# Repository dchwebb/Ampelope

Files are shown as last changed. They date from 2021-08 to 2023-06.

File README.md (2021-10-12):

# Ampelope
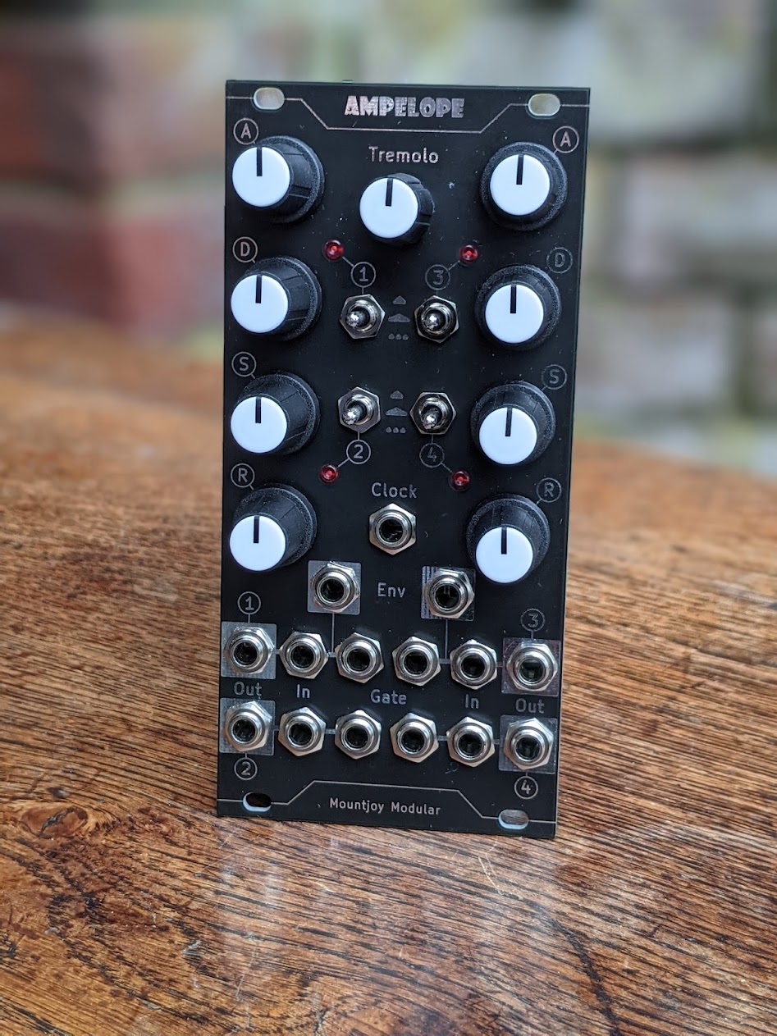
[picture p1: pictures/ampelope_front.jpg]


Overview
--------

Ampelope is a four-channel combined envelope and VCA Eurorack module incorporating a tremolo effect. Each channel can be switched between a fast envelope time, a slow envelope time or a slow envelope with a sine tremolo modulating volume.

The envelopes are loosely modelled on an analog envelope (Roland System 100 type circuit) and feature analog correct capacitor charge/discharge characteristics.

Channels 1 and 2 share the same Attack/Decay/Sustain/Release (ADSR) controls, as do channels 3 and 4. This makes the module particularly suited to dual stereo operation. However each channel has its own gate control allowing independent control of four signals.

The gate controls are normalled in a cascade configuration. For example in dual stereo use gate 1 will be normalled to gate 2 and then a separate gate applied to channel 3 will control channels 3 and 4. In addition gate 1 is normalled to the Doepfer standard gate signal on the 16 pin Eurorack header.

The tremolo control can be clocked or free-run. When clocked the Tremolo potentiometer sets the speed of the tremolo to a multiple of the clock. The tremolo effect applies a sine wave modulation to the envelope.

In addition to the envlopes internal connection to the VCA, envelopes 1 and 3 are available on the front panel and envelopes 2 and 4 on a pin header on the back.

Technical
---------
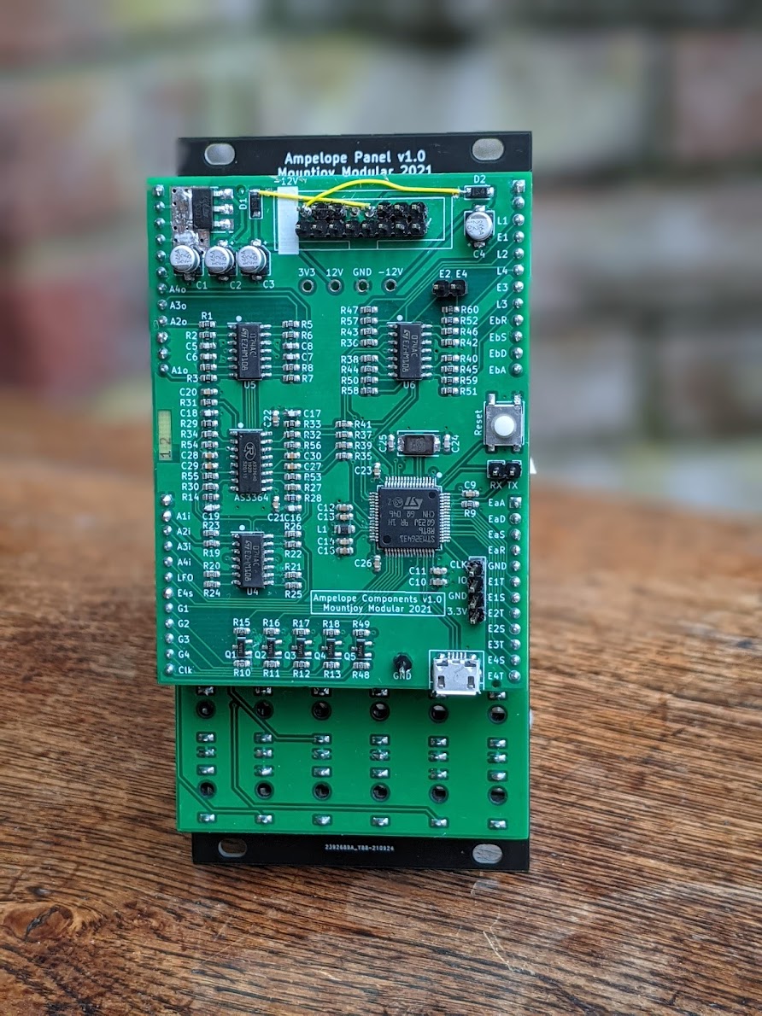
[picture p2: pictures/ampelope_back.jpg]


The module is controlled by an STM32G431 microcontroller which contains four 12-bit DACs. These are used to generate the four envelopes.

The MCU runs at 170MHz and the envelopes samples are generated at 48kHz. The front panel potentiometers are digitised using the MCU's internal ADC. The MCU features a hardware CORDIC peripheral which is used to generate the exponential curves used to model an analog envelopes capacitor charge/discharge characteristics. The CORDIC co-processor is also used to generate the tremolo sine wave.

The MCU's USB peripheral is also connected on the reverse for configuration and upgrade purposes.

The VCA used is an Alpha AS3364 quad linear VCA IC (https://www.alfarzpp.lv/eng/sc/AS3364.php). The MCU outputs the envelopes via its internal DACs at 0V to 3.3V range. This is scaled to 0V to 2V which is the VCA fully closed/fully open range. The envelopes are also amplified to 0V to 8V for control of external modules.

Three TL074 op-amps handle buffering and amplification. NPN transistors provide voltage limiting to incoming gates. The power supply uses a linear regulator to generate the 3.3V digital and analog voltages used by the MCU.

Construction
------------

The module uses a 3 stacked PCB configuration. The components sit on a 4-layer daughter board connected with headers to the 2 layer control PCB holding the LEDs, potentiometers, switches and sockets. This is then bolted to the front panel, also constructed as a 2 layer PCB.

All schematic and PCB layout carried out in Kicad version 5.99.

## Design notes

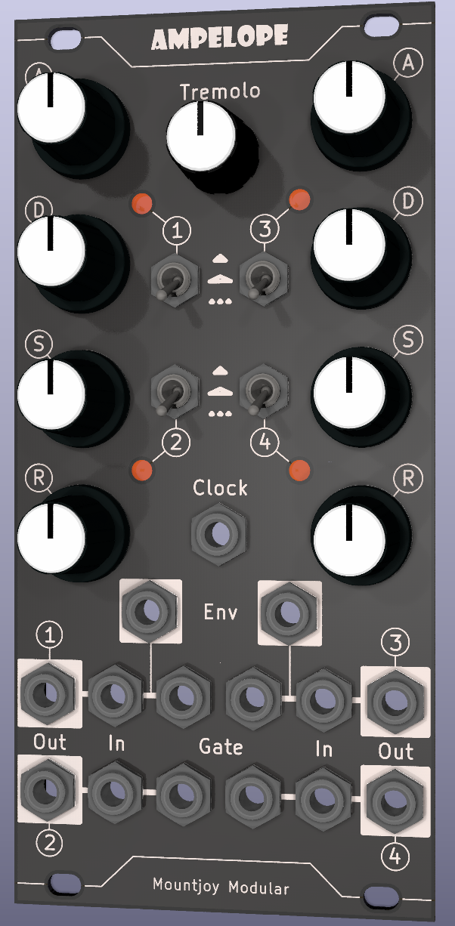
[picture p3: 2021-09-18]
Hardware/Graphics/Ampelope_Panel.png

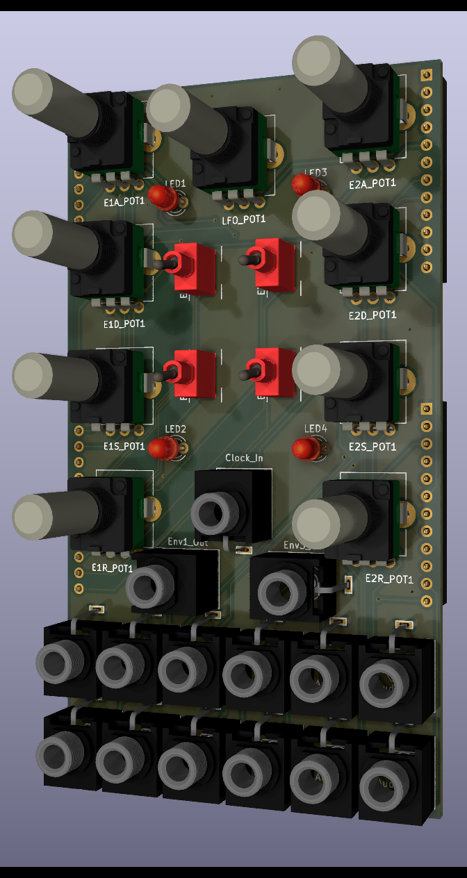
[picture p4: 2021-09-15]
Hardware/Graphics/Ampelope_Controls.png

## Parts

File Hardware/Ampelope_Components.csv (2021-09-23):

Source: | D:\Eurorack\Ampelope\Hardware\Ampelope_Components.kicad_sch
Date: | 22/09/2021 17:17:07
Tool: | Eeschema (5.99.0-12348-g4b436fb86d)
Generator: | C:\Program Files\KiCad\5.99\bin\scripting\plugins/bom_csv_grouped_by_value_with_fp.py
Component Count: | 121
Ref | Qnty | Value | Cmp name | Footprint | Description | Vendor
C1, C2, C3, C4, | 4 | 22uF | CP_Small | Capacitor_SMD:CP_Elec_4x5.8 | Polarized capacitor, small symbol
C5, C6, C7, C8, | 4 | 100pF | C_Small | Capacitor_SMD:C_0603_1608Metric_Pad1.08x0.95mm_HandSolder | Unpolarized capacitor, small symbol
C9, C11, C13, C21, C22, C23, C26, | 7 | 100nF | C_Small | Capacitor_SMD:C_0603_1608Metric_Pad1.08x0.95mm_HandSolder | Unpolarized capacitor, small symbol
C10, | 1 | 4.7uF | C_Small | Capacitor_SMD:C_0603_1608Metric_Pad1.08x0.95mm_HandSolder | Unpolarized capacitor, small symbol
C12, C15, | 2 | 1uF | C_Small | Capacitor_SMD:C_0603_1608Metric_Pad1.08x0.95mm_HandSolder | Unpolarized capacitor, small symbol
C14, C20, | 2 | 10nF | C_Small | Capacitor_SMD:C_0603_1608Metric_Pad1.08x0.95mm_HandSolder | Unpolarized capacitor, small symbol
C16, C17, C18, C19, | 4 | 560pF | C_Small | Capacitor_SMD:C_0603_1608Metric_Pad1.08x0.95mm_HandSolder | Unpolarized capacitor, small symbol
C24, C25, | 2 | 30pF | C_Small | Capacitor_SMD:C_0603_1608Metric_Pad1.08x0.95mm_HandSolder | Unpolarized capacitor, small symbol
C27, C28, C29, C30, | 4 | 2.2nF | C_Small | Capacitor_SMD:C_0603_1608Metric_Pad1.08x0.95mm_HandSolder | Unpolarized capacitor, small symbol
D1, D2, | 2 | 1N5819 | 1N5819 | Diode_SMD:D_SOD-123 | 40V 1A Schottky Barrier Rectifier Diode, DO-41
FID1, | 1 | 4_Layer_Marker | Fiducial | Custom_Footprints:4_Layer_Markers | Fiducial Marker
J1, J2, J3, J4, | 4 | Conn_01x12_Male | Conn_01x12_Male | Connector_PinHeader_2.54mm:PinHeader_1x12_P2.54mm_Vertical | Generic connector, single row, 01x12, script generated (kicad-library-utils/schlib/autogen/connector/)
J5, | 1 | Eurorack_16_pin_power | Eurorack_16_pin_power | Custom_Footprints:Eurorack_16_pin_header
J6, J9, | 2 | Conn_01x02_Male | Conn_01x02_Male | Connector_PinHeader_2.54mm:PinHeader_1x02_P2.54mm_Vertical | Generic connector, single row, 01x02, script generated (kicad-library-utils/schlib/autogen/connector/)
J7, | 1 | SWD_Header | Conn_01x04_Male | Custom_Footprints:SWD_header | Generic connector, single row, 01x04, script generated (kicad-library-utils/schlib/autogen/connector/)
J8, | 1 | USB_B_Micro | USB_B_Micro | Custom_Footprints:USB_Micro-B_Amphenol | USB Micro Type B connector
L1, | 1 | L_Small | L_Small | Inductor_SMD:L_0805_2012Metric_Pad1.05x1.20mm_HandSolder | Inductor, small symbol
Q1, Q2, Q3, Q4, Q5, | 5 | MMBT3906 | MMBT3906 | Package_TO_SOT_SMD:SOT-23 | -0.2A Ic, -40V Vce, Small Signal PNP Transistor, SOT-23
R1, R3, R5, R7, R47, R50, R51, R52, R57, R58, R59, R60, | 12 | 1k | R_Small | Resistor_SMD:R_0603_1608Metric_Pad0.98x0.95mm_HandSolder | Resistor, small symbol
R2, R4, R6, R8, R27, R30, R32, R34, | 8 | 30k | R_Small | Resistor_SMD:R_0603_1608Metric_Pad0.98x0.95mm_HandSolder | Resistor, small symbol
R9, | 1 | 100k | R_Small | Resistor_SMD:R_0603_1608Metric_Pad0.98x0.95mm_HandSolder | Resistor, small symbol
R10, R11, R12, R13, R15, R16, R17, R18, R43, R44, R45, R46, R48, R49, | 14 | 4k7 | R_Small | Resistor_SMD:R_0603_1608Metric_Pad0.98x0.95mm_HandSolder | Resistor, small symbol
R14, R28, R29, R33, | 4 | 510R | R_Small | Resistor_SMD:R_0603_1608Metric_Pad0.98x0.95mm_HandSolder | Resistor, small symbol
R19, R20, R21, R22, R23, R24, R25, R26, R53, R54, R55, R56, | 12 | 10k | R_Small | Resistor_SMD:R_0603_1608Metric_Pad0.98x0.95mm_HandSolder | Resistor, small symbol
R31, | 1 | 100R | R_Small | Resistor_SMD:R_0603_1608Metric_Pad0.98x0.95mm_HandSolder | Resistor, small symbol
R35, R37, R39, R41, | 4 | 6k8 | R_Small | Resistor_SMD:R_0603_1608Metric_Pad0.98x0.95mm_HandSolder | Resistor, small symbol
R36, R38, R40, R42, | 4 | 3k3 | R_Small | Resistor_SMD:R_0603_1608Metric_Pad0.98x0.95mm_HandSolder | Resistor, small symbol
RESET1, | 1 | SW_Push | SW_Push | Custom_Footprints:SW_SPST_EVQQ2 | Push button switch, generic, two pins
TP1, TP2, TP3, TP4, TP5, | 5 | TestPoint | TestPoint | Custom_Footprints:1.3mm_Test_Point | test point
U1, | 1 | STM32G431RB | STM32G431RB | Package_QFP:LQFP-64_10x10mm_P0.5mm | ARM Cortex-M4 MCU, 128KB flash, 32KB RAM, 170MHz, 1.8-3.6V, 50 GPIO, LQFP-64
U2, | 1 | AS3364 | SSI2164 | Package_SO:SOIC-16_3.9x9.9mm_P1.27mm | Quad VCA, SOIC-16
U3, | 1 | LM1117-3.3 | LM1117-3.3 | Package_TO_SOT_SMD:SOT-223-3_TabPin2 | 800mA Low-Dropout Linear Regulator, 3.3V fixed output, TO-220/TO-252/TO-263/SOT-223
U4, U5, U6, | 3 | TL074 | TL074 | Package_SO:SOIC-14_3.9x8.7mm_P1.27mm | Quad Low-Noise JFET-Input Operational Amplifiers, DIP-14/SOIC-14
Y1, | 1 | 8MHz 20pF | Crystal | Crystal:Crystal_SMD_0603-2Pin_6.0x3.5mm | Two pin crystal

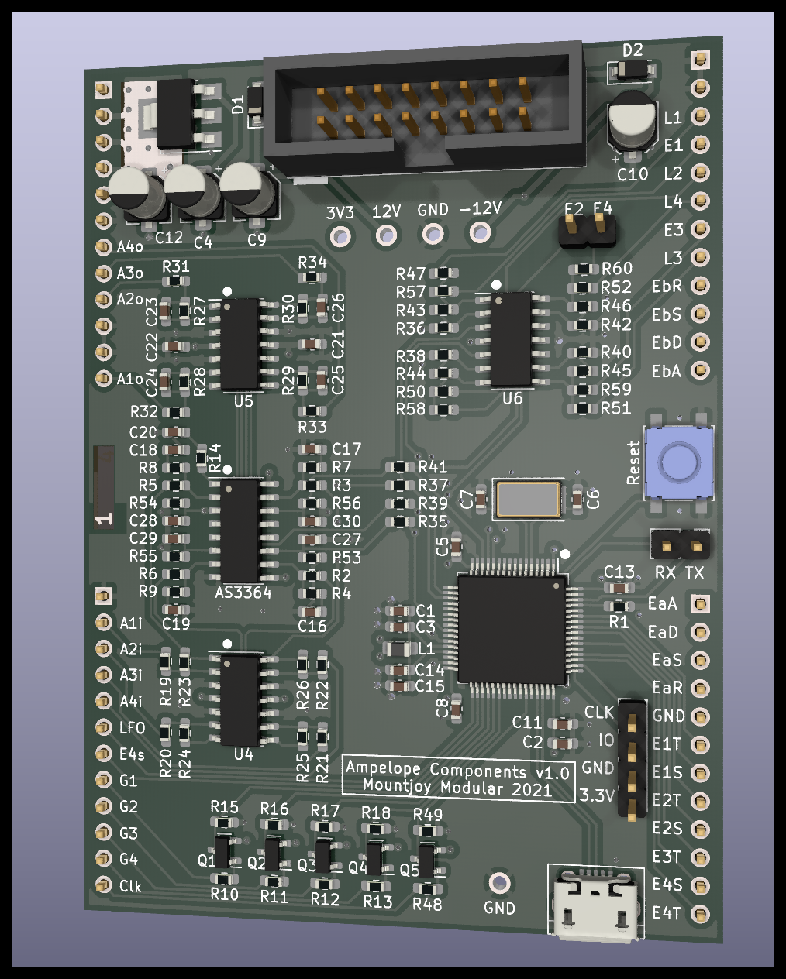
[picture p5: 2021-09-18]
Hardware/Graphics/Ampelope_Components.png

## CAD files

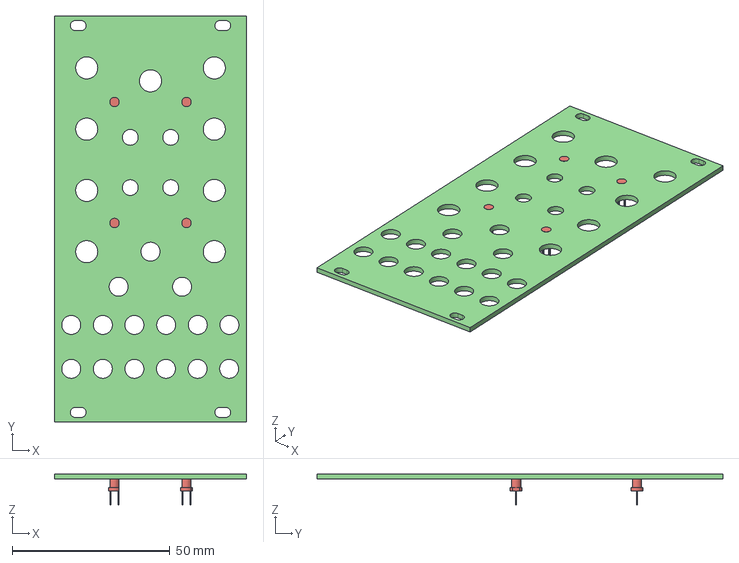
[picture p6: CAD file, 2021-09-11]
Hardware/3d_models/Ampelope_Panel.step
60.8 x 128.5 x 9.80 mm

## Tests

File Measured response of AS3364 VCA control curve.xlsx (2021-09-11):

ctl | output
0 | 0
0.25 | 0.2
0.5 | 1.21
0.75 | 2.8
1 | 4.41
1.25 | 5.89
1.5 | 7.33
1.75 | 8.46
2 | 9.04
Max at around 1.95V
Original signal: 9.65V

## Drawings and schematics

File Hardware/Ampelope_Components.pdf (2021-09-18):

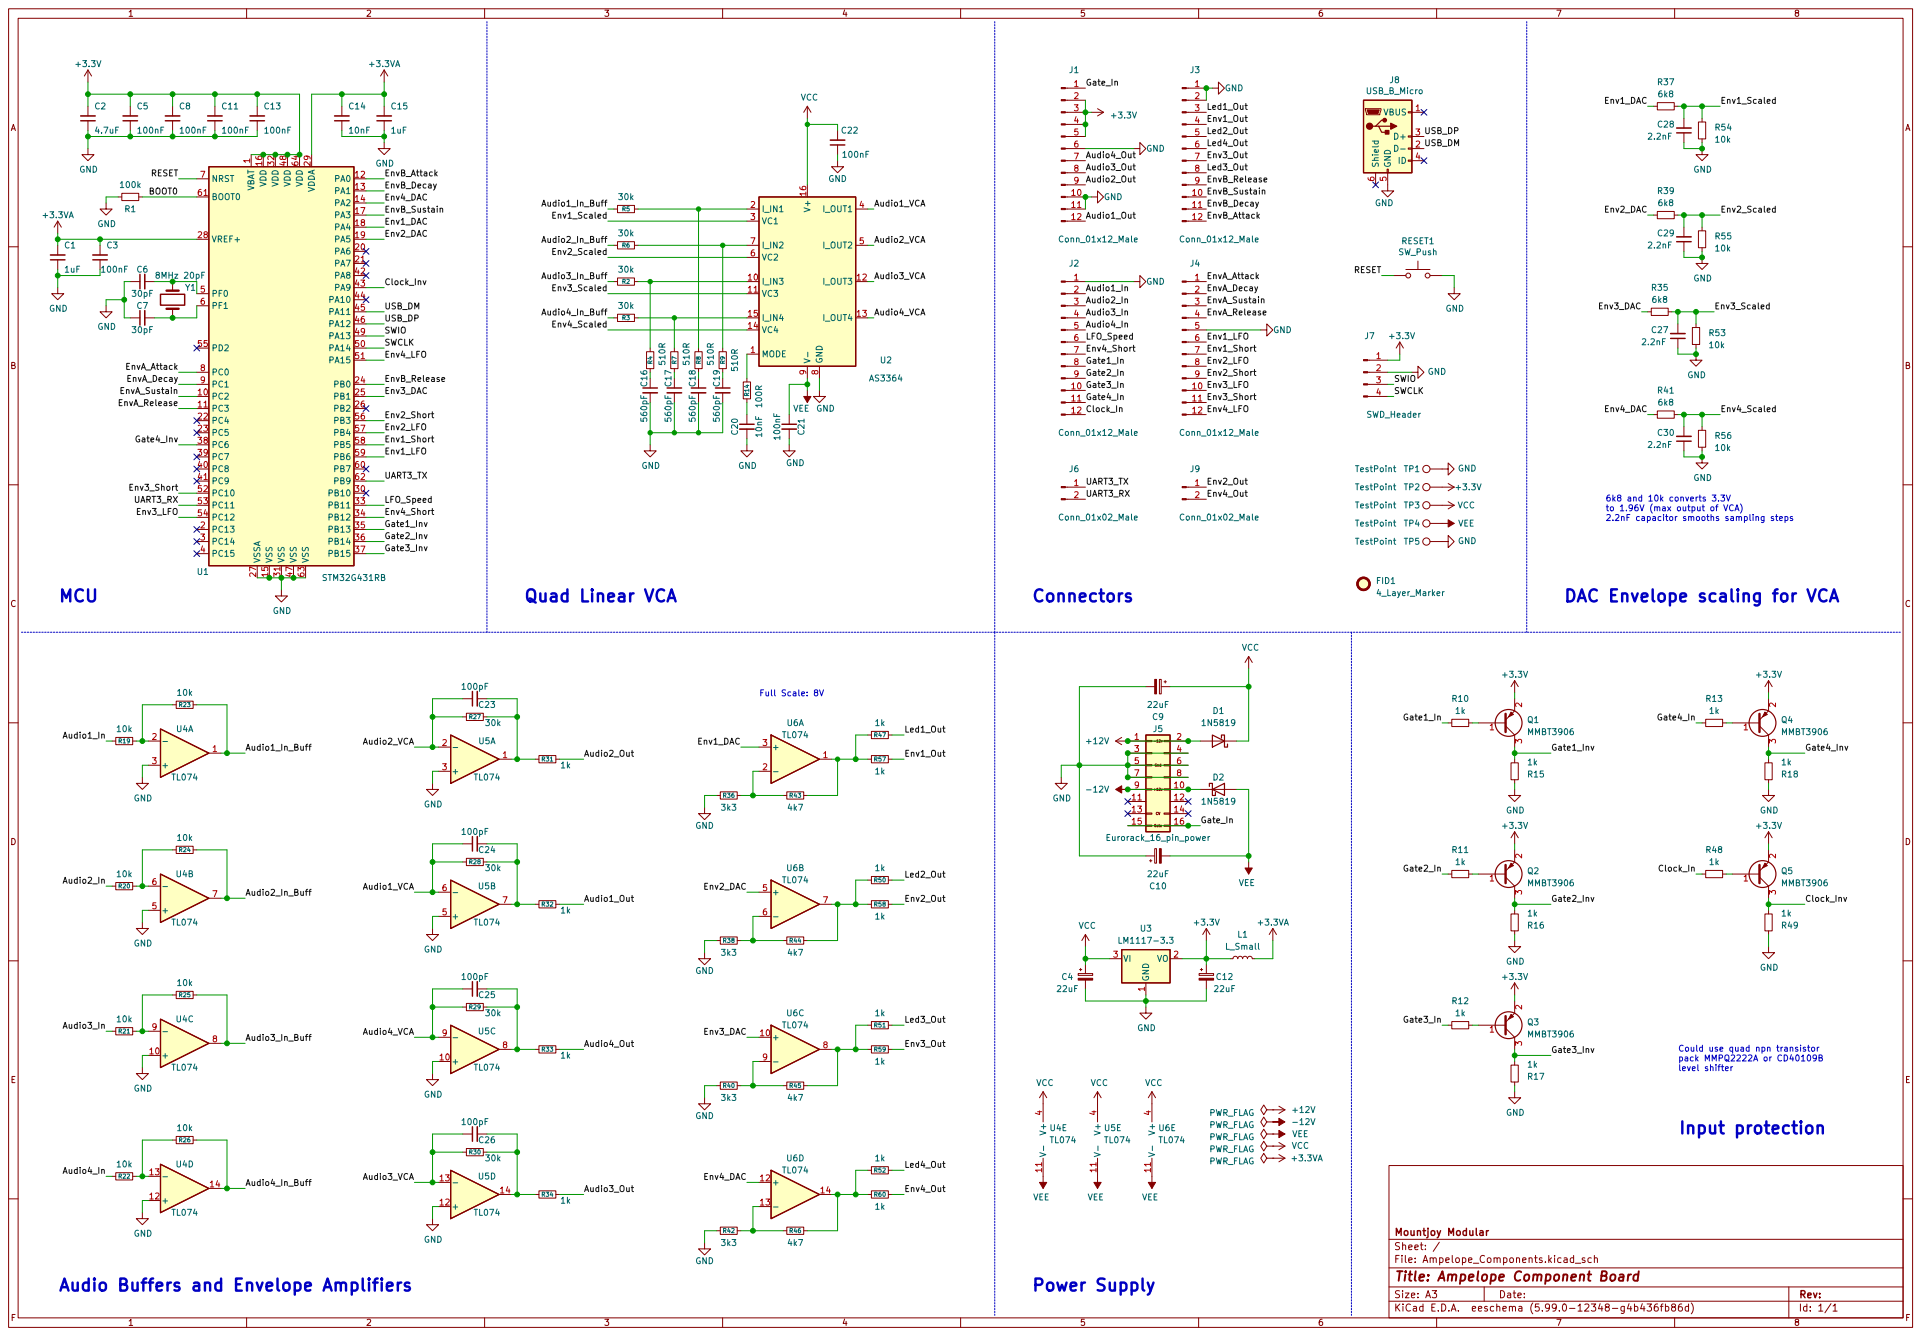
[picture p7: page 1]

1 PC2 10 PC3 11 PA0 12 PA1 13 PA2 14 VSS 15 VDD 16 PA3 17 PA4 18 PA5 19 PC13 2 PA6 20 PA7 21 PC4 22 PC5 23 PB0 24 PB1 25 PB2 26 VSSA 27 VDDA 29 PC14 3 PB10 30 VSS 31 VDD 32 PB12 34 PB13 35 PB14 36 PB15 37 PC6 38 PC7 39 PC15 4 PC8 40 PC9 41 PA8 42 PA9 43 PA10 44 PA11 45 PA12 46 VSS 47 VDD 48 PA13 49 PF0 5 PA14 50 PA15 51 PC10 52 PC11 53 PC12 54 PD2 55 PB3 56 PB4 57 PB5 58 PB6 59 PF1 6 PB7 60 BOOT0 61 PB9 62 VSS 63 VDD 64 NRST 7 PC0 8 PC1 9U1 STM32G431RB

6k8 and 10k converts 3.3V
to 1.96V (max output of VCA)
2.2nF capacitor smooths sampling steps

level shifter DAC Envelope scaling for VCA

R21 10k GND
Audio4_Out Audio Buffers and Envelope Amplifiers

Could use quad npn transistor
pack MMPQ2222A or CD40109B

File: Ampelope_Components.kicad_sch Sheet: / Mountjoy Modular

Id: 1/1 Title: Ampelope Component Board

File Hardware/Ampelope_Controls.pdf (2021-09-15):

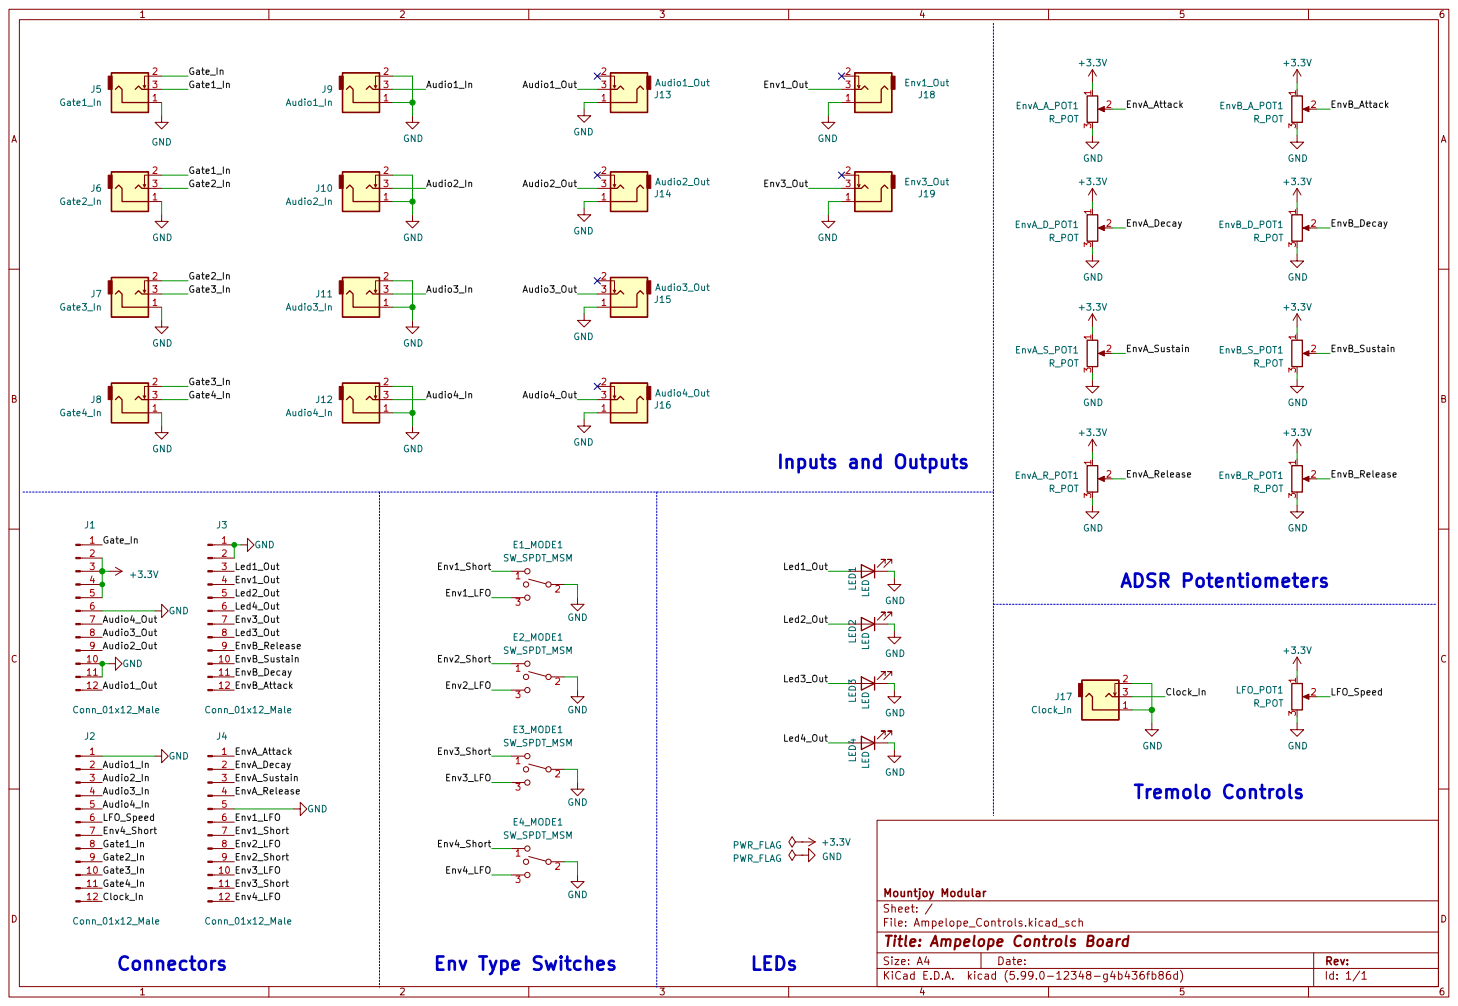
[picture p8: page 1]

3 EnvA_R_POT1 R_POT GND LED4 LED GND LED3 LED GND GND

Id: 1/1 Title: Ampelope Controls Board

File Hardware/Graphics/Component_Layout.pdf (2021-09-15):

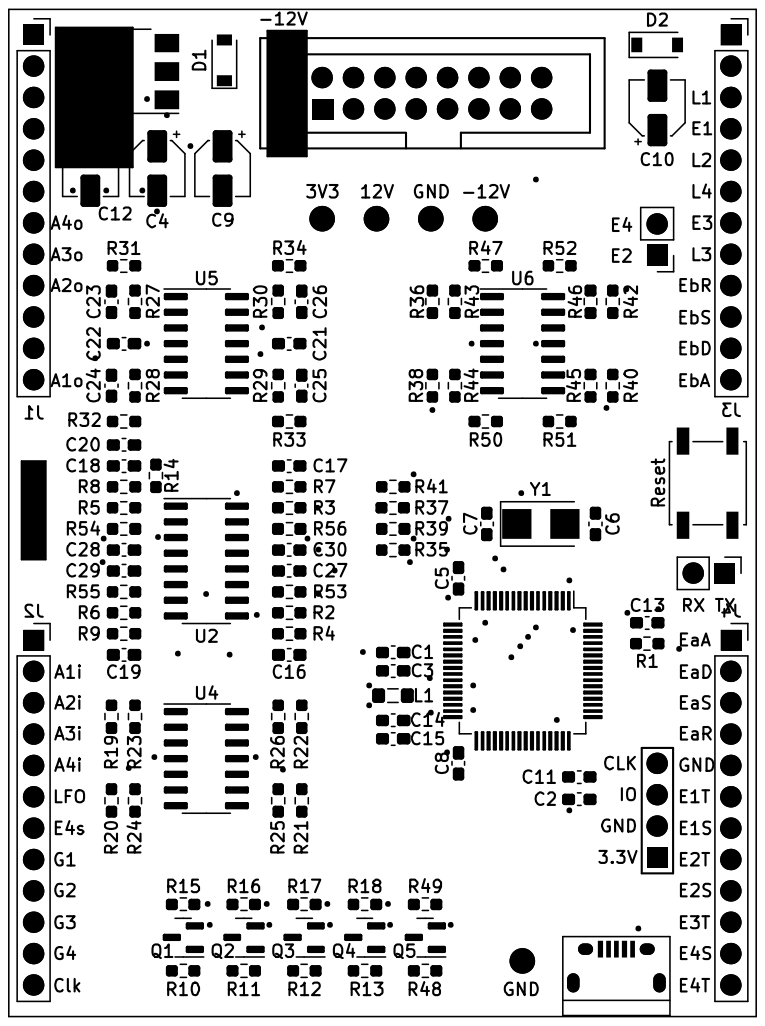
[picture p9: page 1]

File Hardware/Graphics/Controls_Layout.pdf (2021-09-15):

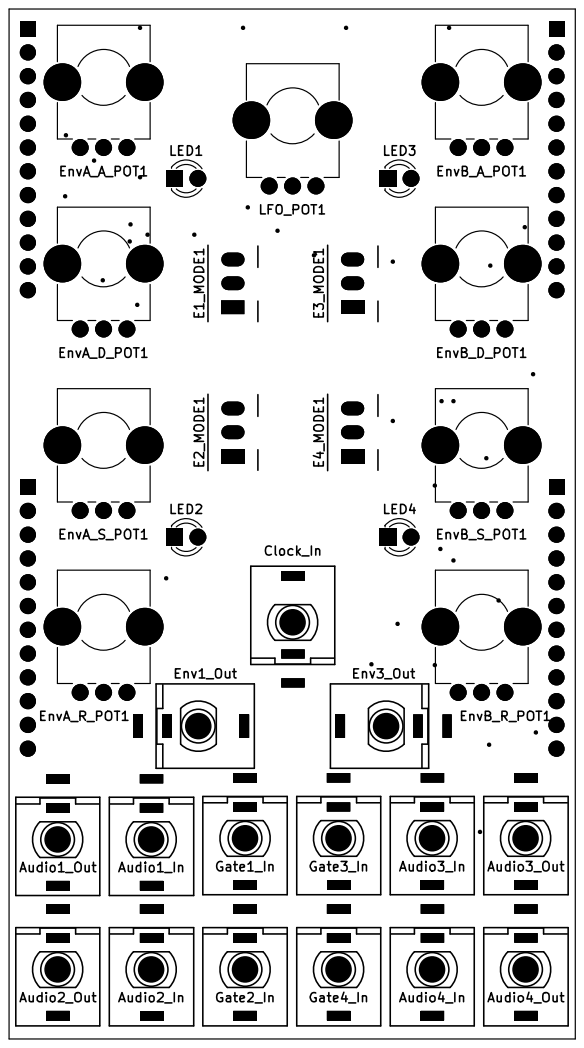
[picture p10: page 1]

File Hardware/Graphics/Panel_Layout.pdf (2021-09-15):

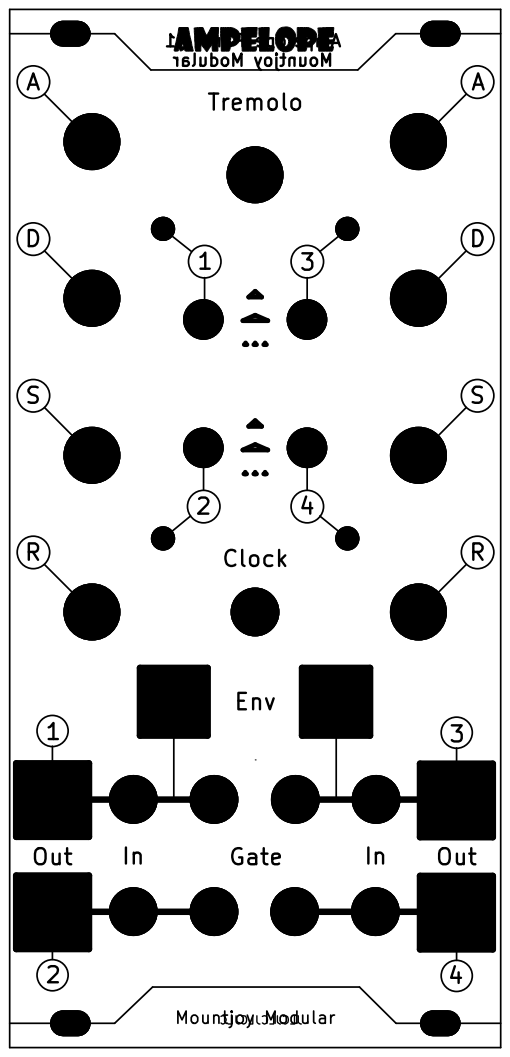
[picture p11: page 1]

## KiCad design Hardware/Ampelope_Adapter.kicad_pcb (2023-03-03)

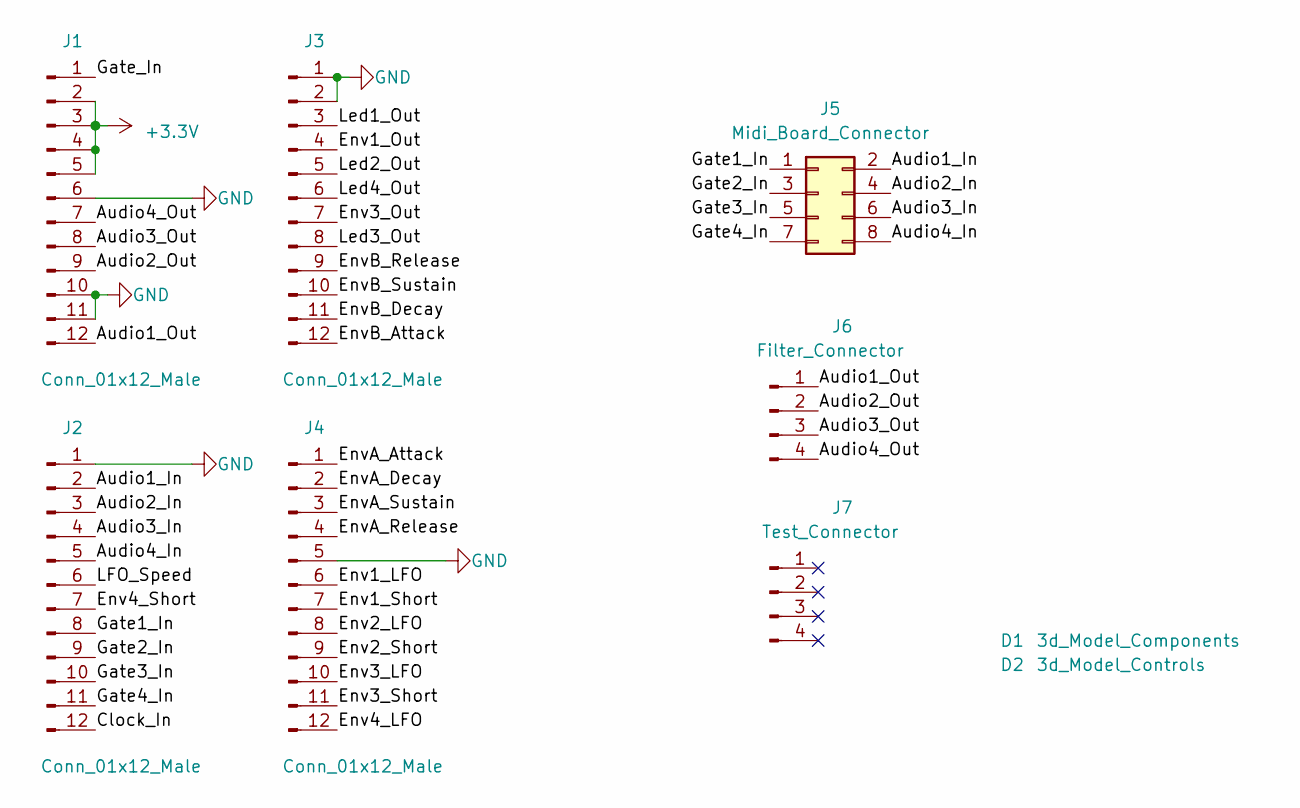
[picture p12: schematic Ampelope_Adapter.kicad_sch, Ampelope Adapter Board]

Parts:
D1: 3d_Model_Components; 3D_Dummy
D2: 3d_Model_Controls; 3D_Dummy
J1, J2, J3, J4: Conn_01x12_Male; PinSocket_1x12_P2.54mm_Vertical
J5: Midi_Board_Connector; PinHeader_2x04_P2.54mm_Vertical
J6: Filter_Connector; PinHeader_1x04_P2.54mm_Vertical
J7: Test_Connector; PinHeader_1x04_P2.54mm_Vertical

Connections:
+3V3: J1.2, J1.3, J1.4, J1.5
/Audio1_In: J2.2, J5.2
/Audio1_Out: J1.12, J6.1
/Audio2_In: J2.3, J5.4
/Audio2_Out: J1.9, J6.2
/Audio3_In: J2.4, J5.6
/Audio3_Out: J1.8, J6.3
/Audio4_In: J2.5, J5.8
/Audio4_Out: J1.7, J6.4
/Clock_In: J2.12
/Env1_LFO: J4.6
/Env1_Out: J3.4
/Env1_Short: J4.7
/Env2_LFO: J4.8
/Env2_Short: J4.9
/Env3_LFO: J4.10
/Env3_Out: J3.7
/Env3_Short: J4.11
/Env4_LFO: J4.12
/Env4_Short: J2.7
/EnvA_Attack: J4.1
/EnvA_Decay: J4.2
/EnvA_Release: J4.4
/EnvA_Sustain: J4.3
/EnvB_Attack: J3.12
/EnvB_Decay: J3.11
/EnvB_Release: J3.9
/EnvB_Sustain: J3.10
/Gate1_In: J2.8, J5.1
/Gate2_In: J2.9, J5.3
/Gate3_In: J2.10, J5.5
/Gate4_In: J2.11, J5.7
/Gate_In: J1.1
/LFO_Speed: J2.6
/Led1_Out: J3.3
/Led2_Out: J3.5
/Led3_Out: J3.8
/Led4_Out: J3.6
GND: J1.6, J1.10, J1.11, J2.1, J3.1, J3.2, J4.5

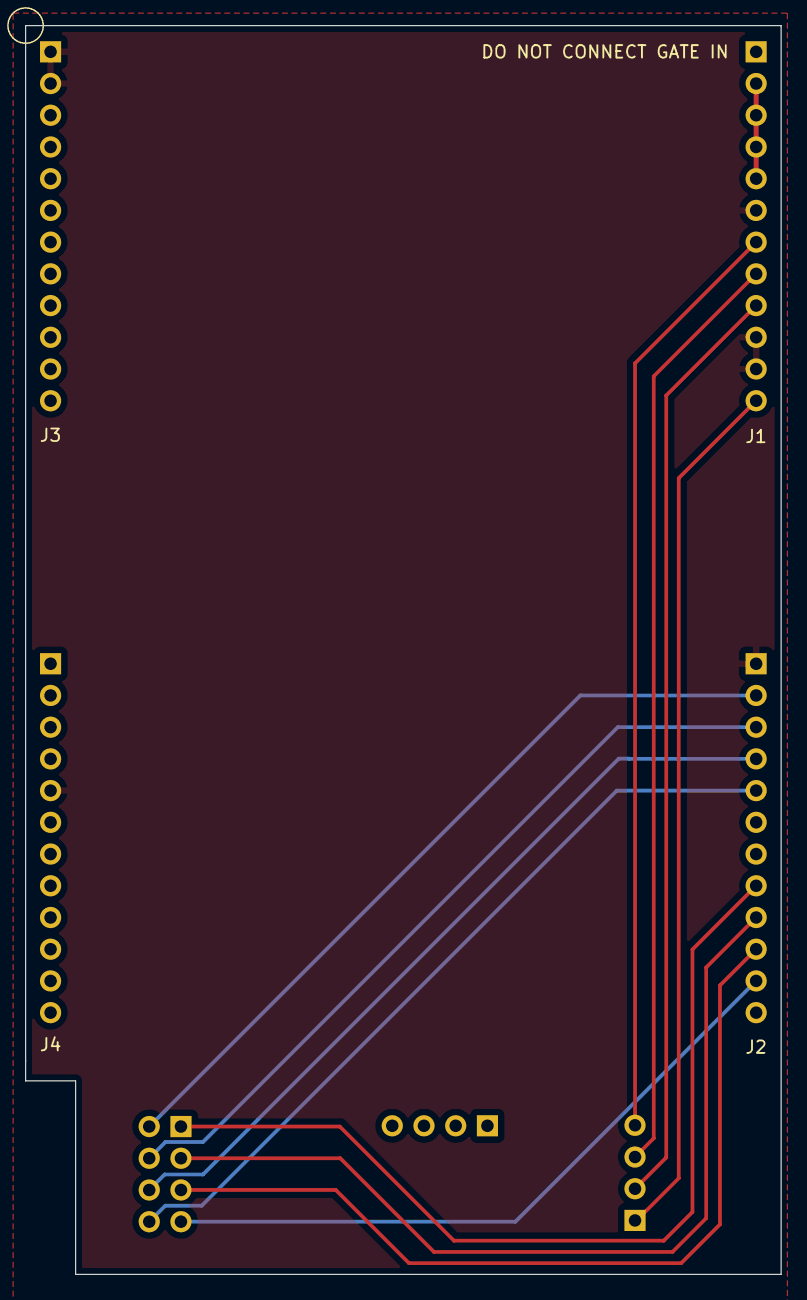
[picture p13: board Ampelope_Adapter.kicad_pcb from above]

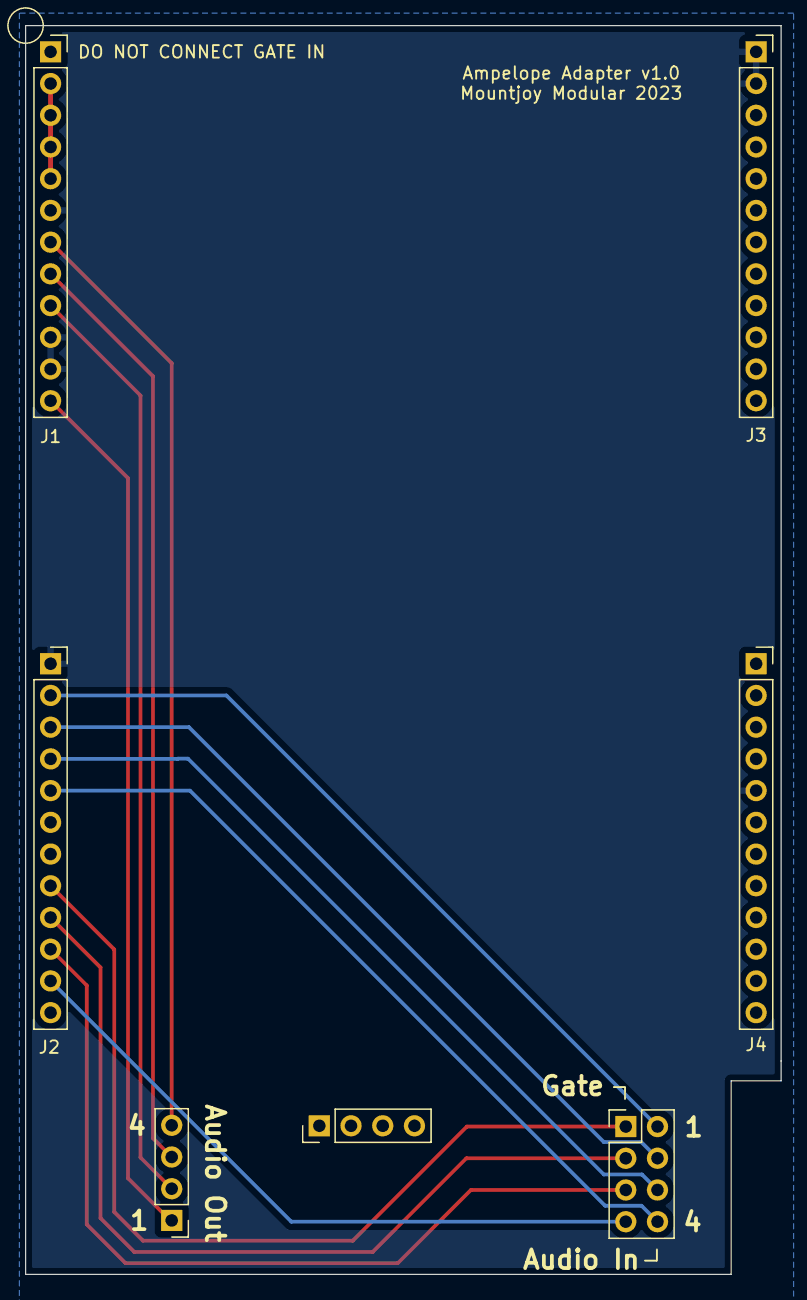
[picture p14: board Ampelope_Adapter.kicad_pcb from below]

Board: 2 copper layers, 60.5 x 100.0 mm, 9 parts (8 on the bottom side), 14 nets.

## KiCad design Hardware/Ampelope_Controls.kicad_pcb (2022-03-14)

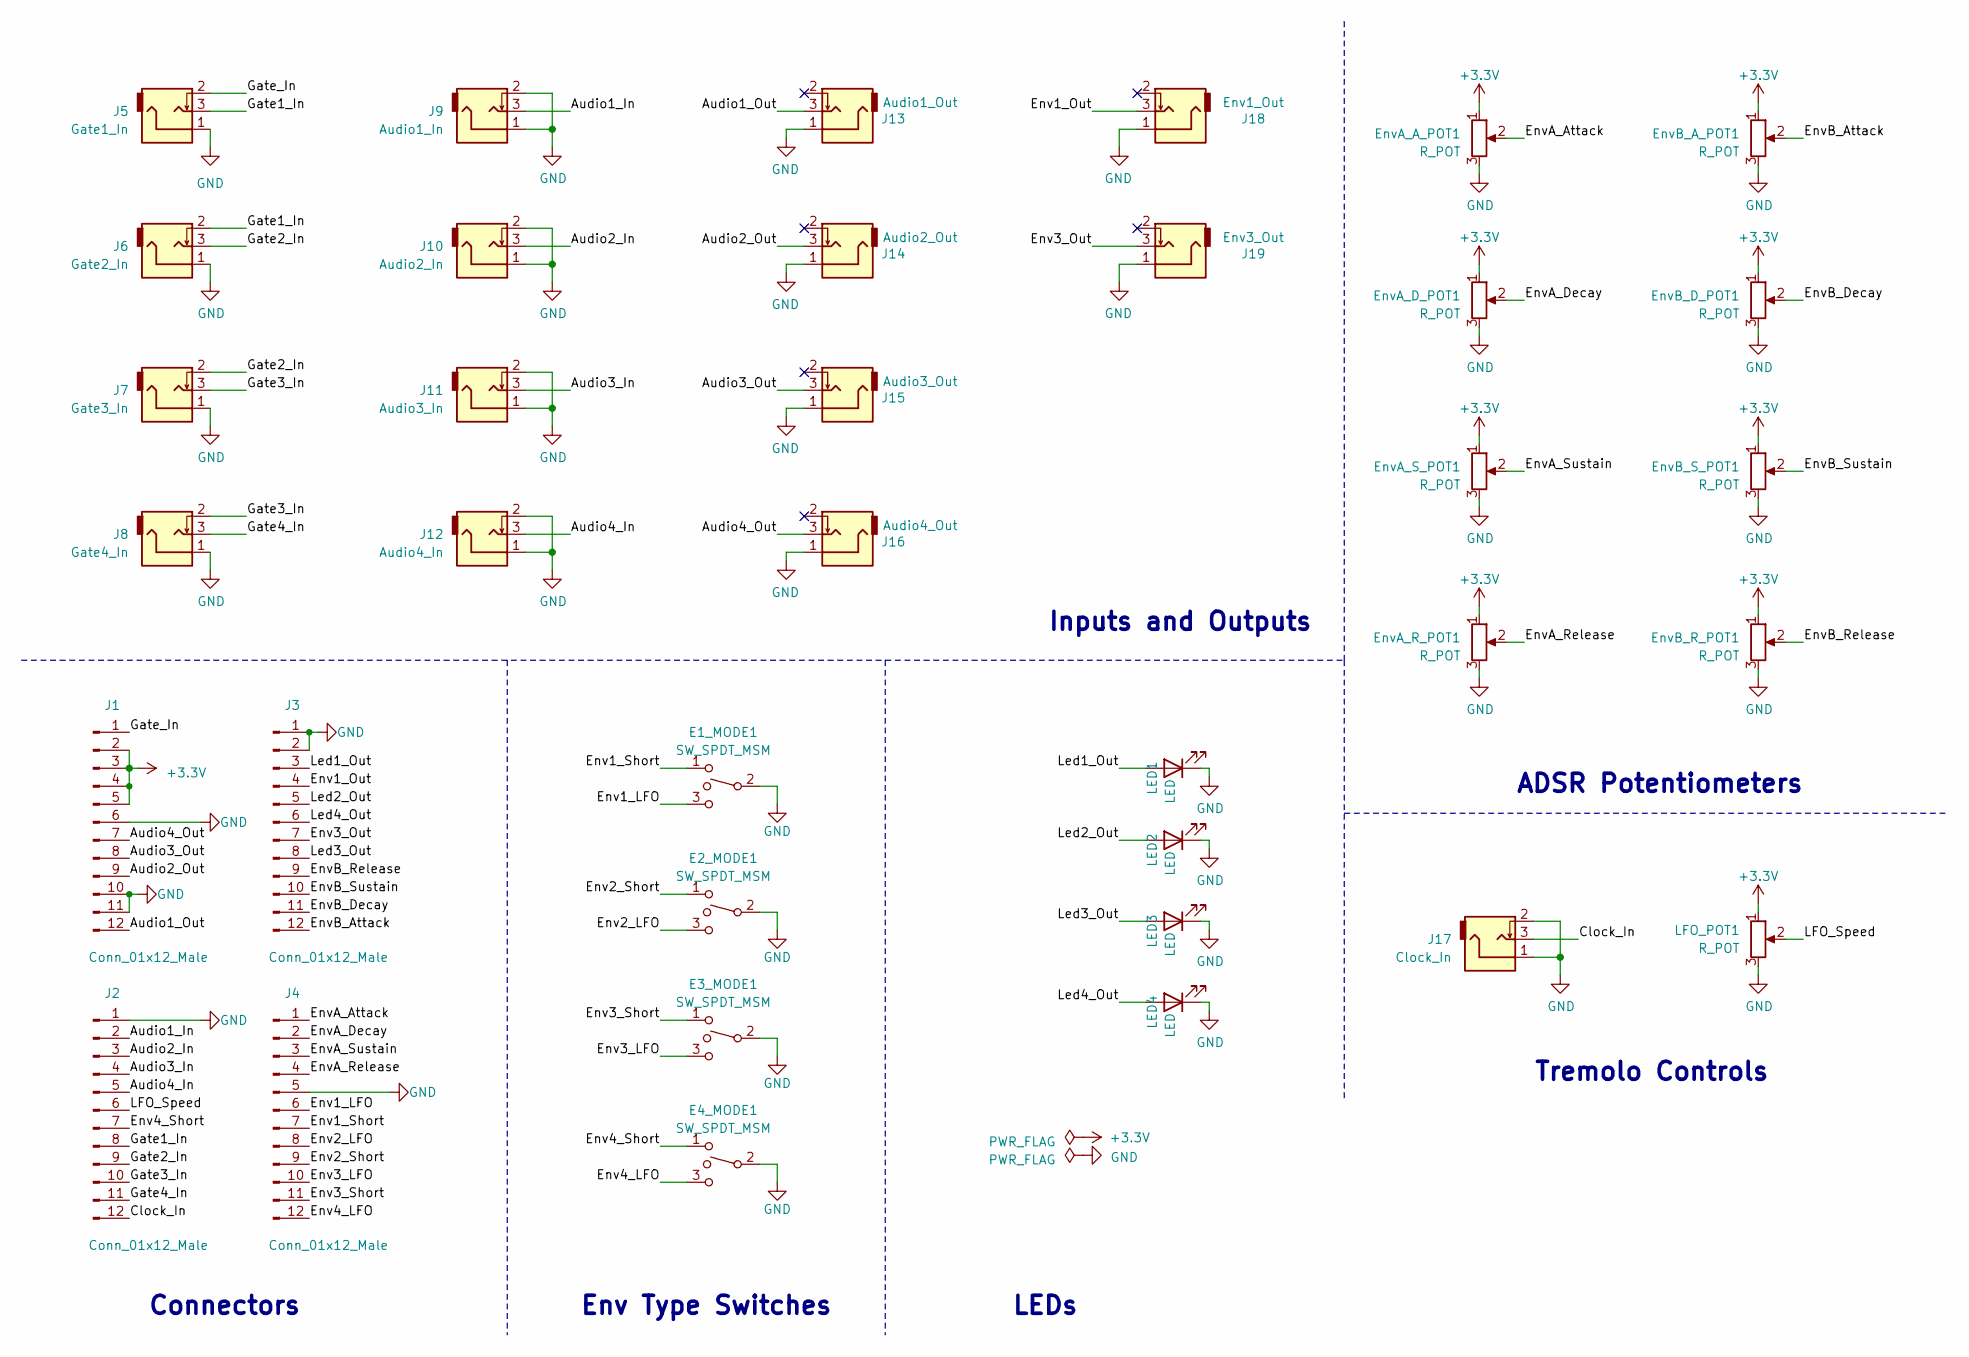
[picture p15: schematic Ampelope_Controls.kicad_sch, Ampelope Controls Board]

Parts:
E1_MODE1, E2_MODE1, E3_MODE1, E4_MODE1: SW_SPDT_MSM; SPDT_SubMiniature_Aligned
EnvA_A_POT1: R_POT; Alpha_9mm_Potentiometer_Aligned
EnvA_D_POT1: R_POT; Alpha_9mm_Potentiometer_Aligned
EnvA_R_POT1: R_POT; Alpha_9mm_Potentiometer_Aligned
EnvA_S_POT1: R_POT; Alpha_9mm_Potentiometer_Aligned
EnvB_A_POT1: R_POT; Alpha_9mm_Potentiometer_Aligned
EnvB_D_POT1: R_POT; Alpha_9mm_Potentiometer_Aligned
EnvB_R_POT1: R_POT; Alpha_9mm_Potentiometer_Aligned
EnvB_S_POT1: R_POT; Alpha_9mm_Potentiometer_Aligned
J1, J2, J3, J4: Conn_01x12_Male; PinHeader_1x12_P2.54mm_Vertical
J5: Gate1_In; THONKICONN_hole
J6: Gate2_In; THONKICONN_hole
J7: Gate3_In; THONKICONN_hole
J8: Gate4_In; THONKICONN_hole
J9: Audio1_In; THONKICONN_hole
J10: Audio2_In; THONKICONN_hole
J11: Audio3_In; THONKICONN_hole
J12: Audio4_In; THONKICONN_hole
J13: Audio1_Out; THONKICONN_hole
J14: Audio2_Out; THONKICONN_hole
J15: Audio3_Out; THONKICONN_hole
J16: Audio4_Out; THONKICONN_hole
J17: Clock_In; THONKICONN_hole
J18: Env1_Out; THONKICONN_hole
J19: Env3_Out; THONKICONN_hole
LED1, LED2, LED3, LED4: LED; LED_D3.0mm
LFO_POT1: R_POT; Alpha_9mm_Potentiometer_Aligned

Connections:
+3V3: EnvA_A_POT1.1, EnvA_D_POT1.1, EnvA_R_POT1.1, EnvA_S_POT1.1, EnvB_A_POT1.1, EnvB_D_POT1.1, EnvB_R_POT1.1, EnvB_S_POT1.1, J1.2, J1.3, J1.4, J1.5, LFO_POT1.1
/Audio1_In: J2.2, J9.3
/Audio1_Out: J1.12, J13.3
/Audio2_In: J2.3, J10.3
/Audio2_Out: J1.9, J14.3
/Audio3_In: J2.4, J11.3
/Audio3_Out: J1.8, J15.3
/Audio4_In: J2.5, J12.3
/Audio4_Out: J1.7, J16.3
/Clock_In: J2.12, J17.3
/Env1_LFO: E1_MODE1.3, J4.6
/Env1_Out: J3.4, J18.3
/Env1_Short: E1_MODE1.1, J4.7
/Env2_LFO: E2_MODE1.3, J4.8
/Env2_Short: E2_MODE1.1, J4.9
/Env3_LFO: E3_MODE1.3, J4.10
/Env3_Out: J3.7, J19.3
/Env3_Short: E3_MODE1.1, J4.11
/Env4_LFO: E4_MODE1.3, J4.12
/Env4_Short: E4_MODE1.1, J2.7
/EnvA_Attack: EnvA_A_POT1.2, J4.1
/EnvA_Decay: EnvA_D_POT1.2, J4.2
/EnvA_Release: EnvA_R_POT1.2, J4.4
/EnvA_Sustain: EnvA_S_POT1.2, J4.3
/EnvB_Attack: EnvB_A_POT1.2, J3.12
/EnvB_Decay: EnvB_D_POT1.2, J3.11
/EnvB_Release: EnvB_R_POT1.2, J3.9
/EnvB_Sustain: EnvB_S_POT1.2, J3.10
/Gate1_In: J2.8, J5.3, J6.2
/Gate2_In: J2.9, J6.3, J7.2
/Gate3_In: J2.10, J7.3, J8.2
/Gate4_In: J2.11, J8.3
/Gate_In: J1.1, J5.2
/LFO_Speed: J2.6, LFO_POT1.2
/Led1_Out: J3.3, LED1.2 (A)
/Led2_Out: J3.5, LED2.2 (A)
/Led3_Out: J3.8, LED3.2 (A)
/Led4_Out: J3.6, LED4.2 (A)
GND: E1_MODE1.2, E2_MODE1.2, E3_MODE1.2, E4_MODE1.2, EnvA_A_POT1.3, EnvA_D_POT1.3, EnvA_R_POT1.3, EnvA_S_POT1.3, EnvB_A_POT1.3, EnvB_D_POT1.3, EnvB_R_POT1.3, EnvB_S_POT1.3, J1.6, J1.10, J1.11, J2.1, J3.1, J3.2, J4.5, J5.1, J6.1, J7.1, J8.1, J9.1, J9.2, J10.1, J10.2, J11.1, J11.2, J12.1, J12.2, J13.1, J14.1, J15.1, J16.1, J17.1, J17.2, J18.1, J19.1, LED1.1 (K), LED2.1 (K), LED3.1 (K), LED4.1 (K), LFO_POT1.3

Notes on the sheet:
Connectors
Env Type Switches
LEDs
Inputs and Outputs
ADSR Potentiometers
Tremolo Controls

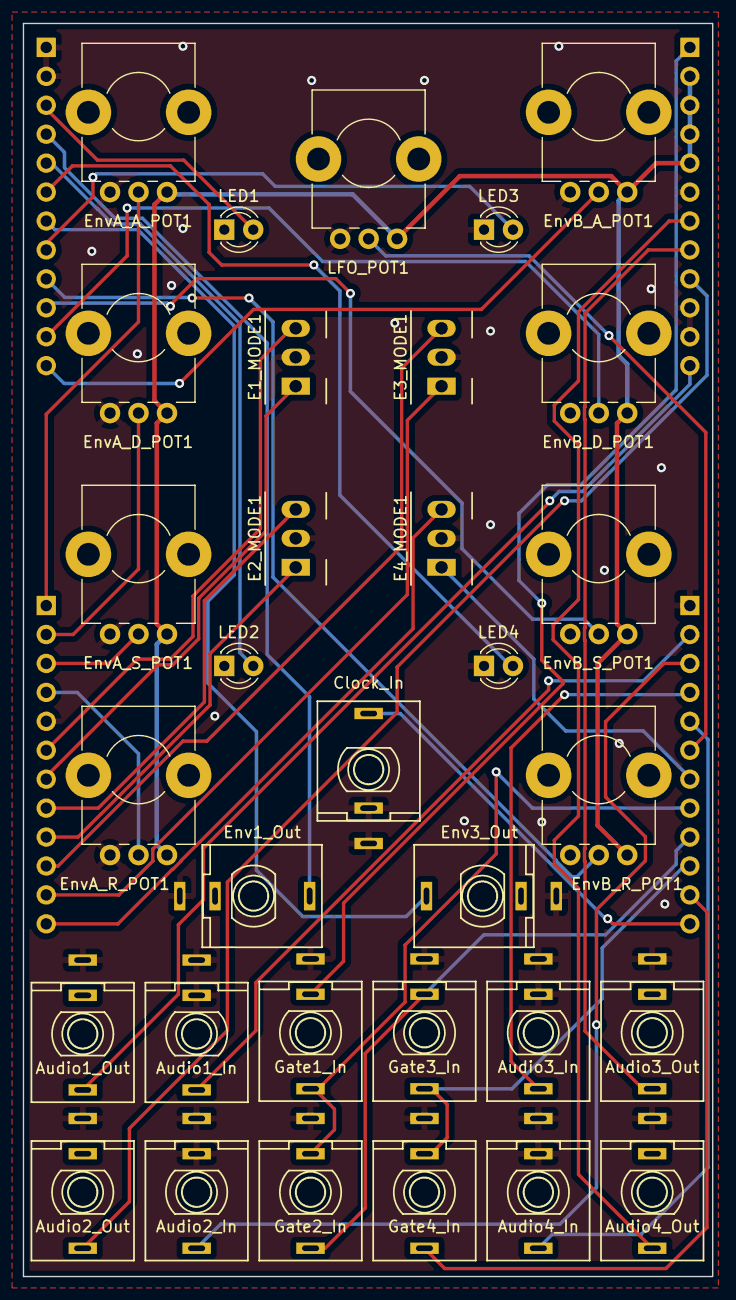
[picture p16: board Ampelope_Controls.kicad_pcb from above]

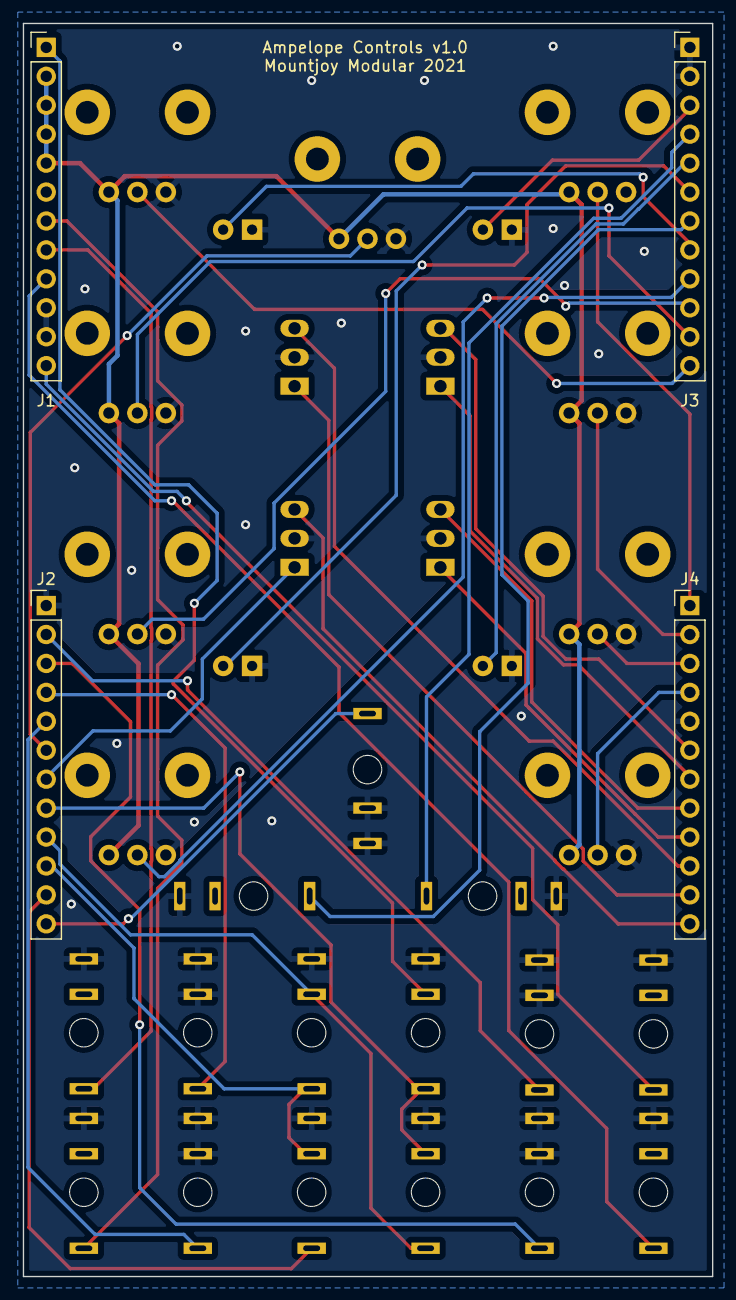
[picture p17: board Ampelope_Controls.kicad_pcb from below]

Board: 2 copper layers, 60.5 x 110.0 mm, 36 parts (4 on the bottom side), 39 nets.

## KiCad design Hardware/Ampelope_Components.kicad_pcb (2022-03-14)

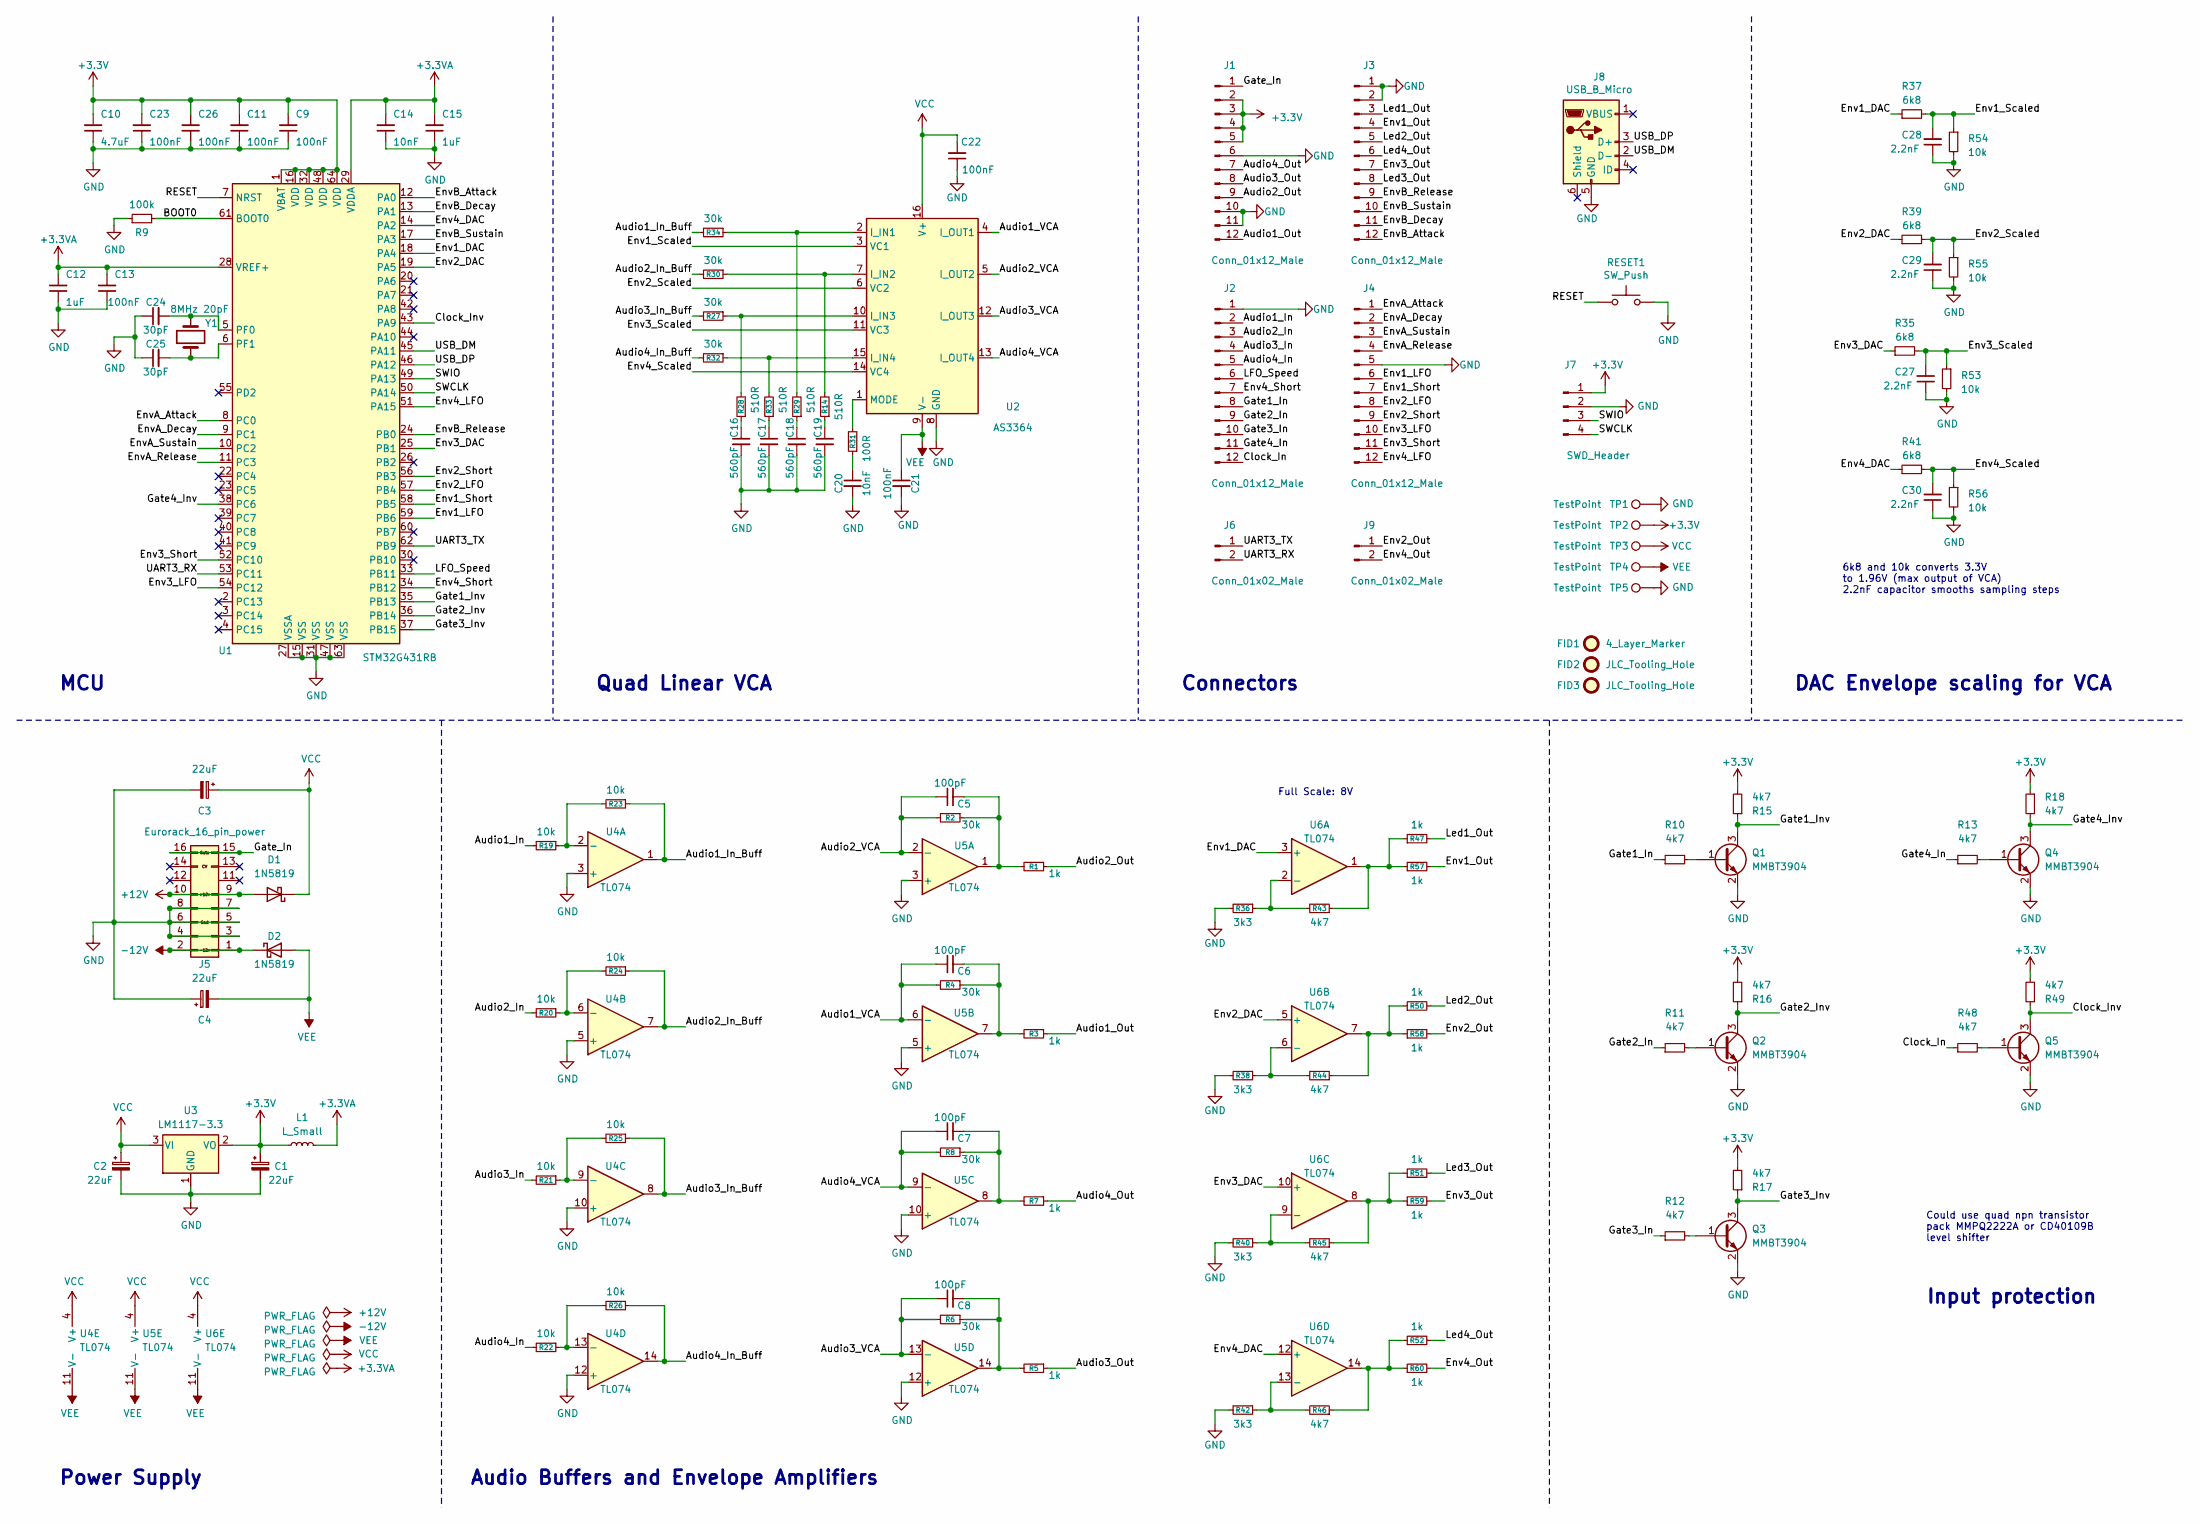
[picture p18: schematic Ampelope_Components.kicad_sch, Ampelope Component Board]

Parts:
C1, C2, C3, C4: 22uF; CP_Elec_4x5.8
C5, C6, C7, C8: 100pF; C_0603_1608Metric_Pad1.08x0.95mm_HandSolder; Part_Number C14858
C9, C11, C13, C21, C22, C23, C26: 100nF; C_0603_1608Metric_Pad1.08x0.95mm_HandSolder; Part_Number C14663
C10: 4.7uF; C_0603_1608Metric_Pad1.08x0.95mm_HandSolder; Part_Number C19666
C12, C15: 1uF; C_0603_1608Metric_Pad1.08x0.95mm_HandSolder; Part_Number C15849
C14, C20: 10nF; C_0603_1608Metric_Pad1.08x0.95mm_HandSolder; Part_Number C57112
C16, C17, C18, C19: 560pF; C_0603_1608Metric_Pad1.08x0.95mm_HandSolder
C24, C25: 30pF; C_0603_1608Metric_Pad1.08x0.95mm_HandSolder; Part_Number C22397
C27, C28, C29, C30: 2.2nF; C_0603_1608Metric_Pad1.08x0.95mm_HandSolder; Part_Number C1604
D1, D2: 1N5819; D_SOD-123
FID1: 4_Layer_Marker; 4_Layer_Markers
FID2, FID3: JLC_Tooling_Hole; JLC_SMT_Tooling_Hole
J1, J2, J3, J4: Conn_01x12_Male; PinHeader_1x12_P2.54mm_Vertical
J5: Eurorack_16_pin_power; Eurorack_16_pin_header
J6, J9: Conn_01x02_Male; PinHeader_1x02_P2.54mm_Vertical
J7: SWD_Header; SWD_header
J8: USB_B_Micro; USB_Micro-B_Amphenol
L1: L_Small; L_0805_2012Metric_Pad1.05x1.20mm_HandSolder; Part_Number C1046
Q1, Q2, Q3, Q4, Q5: MMBT3904; SOT-23; Part_Number C20526
R1, R3, R5, R7, R47, R50, R51, R52, R57, R58, R59, R60: 1k; R_0603_1608Metric_Pad0.98x0.95mm_HandSolder; Part_Number C21190
R2, R4, R6, R8, R27, R30, R32, R34: 30k; R_0603_1608Metric_Pad0.98x0.95mm_HandSolder; Part_Number C22984
R9: 100k; R_0603_1608Metric_Pad0.98x0.95mm_HandSolder; Part_Number C25803
R10, R11, R12, R13, R15, R16, R17, R18, R43, R44, R45, R46, R48, R49: 4k7; R_0603_1608Metric_Pad0.98x0.95mm_HandSolder; Part_Number C23162
R14, R28, R29, R33: 510R; R_0603_1608Metric_Pad0.98x0.95mm_HandSolder; Part_Number C23193
R19, R20, R21, R22, R23, R24, R25, R26, R53, R54, R55, R56: 10k; R_0603_1608Metric_Pad0.98x0.95mm_HandSolder; Part_Number C25804
R31: 100R; R_0603_1608Metric_Pad0.98x0.95mm_HandSolder; Part_Number C22775
R35, R37, R39, R41: 6k8; R_0603_1608Metric_Pad0.98x0.95mm_HandSolder; Part_Number C23212
R36, R38, R40, R42: 3k3; R_0603_1608Metric_Pad0.98x0.95mm_HandSolder; Part_Number C22978
RESET1: SW_Push; SW_SPST_EVQQ2
TP1, TP2, TP3, TP4, TP5: TestPoint; 1.3mm_Test_Point
U1: STM32G431RB; LQFP-64_10x10mm_P0.5mm
U2: AS3364; SOIC-16_3.9x9.9mm_P1.27mm
U3: LM1117-3.3; SOT-223-3_TabPin2
U4, U5, U6: TL074; SOIC-14_3.9x8.7mm_P1.27mm
Y1: 8MHz 20pF; Crystal_SMD_0603-2Pin_6.0x3.5mm; Part_Number C115962

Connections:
+3.3VA: C12.2, C13.2, C14.2, C15.2, L1.2, U1.28 (VREF+), U1.29 (VDDA)
+3V3: C1.1, C9.2, C10.2, C11.2, C23.2, C26.2, J1.2, J1.3, J1.4, J1.5, J7.1, L1.1, R15.2, R16.2, R17.2, R18.1, R49.2, TP2.1, U1.1 (VBAT), U1.16 (VDD), U1.32 (VDD), U1.48 (VDD), U1.64 (VDD), U3.2 (VO)
+12V: D1.2 (A), J5.9, J5.10
-12V: D2.1 (K), J5.1, J5.2
/Audio1_In: J2.2, R19.2
/Audio1_In_Buff: R23.1, R34.2, U4.1
/Audio1_Out: J1.12, R3.1
/Audio1_VCA: C6.1, R4.2, U2.4 (I_OUT1), U5.6 (-)
/Audio2_In: J2.3, R20.2
/Audio2_In_Buff: R24.1, R30.2, U4.7
/Audio2_Out: J1.9, R1.1
/Audio2_VCA: C5.1, R2.2, U2.5 (I_OUT2), U5.2 (-)
/Audio3_In: J2.4, R21.2
/Audio3_In_Buff: R25.1, R27.2, U4.8
/Audio3_Out: J1.8, R5.1
/Audio3_VCA: C8.1, R6.2, U2.12 (I_OUT3), U5.13 (-)
/Audio4_In: J2.5, R22.2
/Audio4_In_Buff: R26.1, R32.2, U4.14
/Audio4_Out: J1.7, R7.1
/Audio4_VCA: C7.1, R8.2, U2.13 (I_OUT4), U5.9 (-)
/BOOT0: R9.2, U1.61 (BOOT0)
/Clock_In: J2.12, R48.1
/Clock_Inv: Q5.3 (C), R49.1, U1.43 (PA9)
/Env1_DAC: R37.1, U1.18 (PA4), U6.3 (+)
/Env1_LFO: J4.6, U1.59 (PB6)
/Env1_Out: J3.4, R57.2
/Env1_Scaled: C28.2, R37.2, R54.1, U2.3 (VC1)
/Env1_Short: J4.7, U1.58 (PB5)
/Env2_DAC: R39.1, U1.19 (PA5), U6.5 (+)
/Env2_LFO: J4.8, U1.57 (PB4)
/Env2_Out: J9.1, R58.2
/Env2_Scaled: C29.2, R39.2, R55.1, U2.6 (VC2)
/Env2_Short: J4.9, U1.56 (PB3)
/Env3_DAC: R35.1, U1.25 (PB1), U6.10 (+)
/Env3_LFO: J4.10, U1.54 (PC12)
/Env3_Out: J3.7, R59.2
/Env3_Scaled: C27.2, R35.2, R53.1, U2.11 (VC3)
/Env3_Short: J4.11, U1.52 (PC10)
/Env4_DAC: R41.1, U1.14 (PA2), U6.12 (+)
/Env4_LFO: J4.12, U1.51 (PA15)
/Env4_Out: J9.2, R60.2
/Env4_Scaled: C30.2, R41.2, R56.1, U2.14 (VC4)
/Env4_Short: J2.7, U1.34 (PB12)
/EnvA_Attack: J4.1, U1.8 (PC0)
/EnvA_Decay: J4.2, U1.9 (PC1)
/EnvA_Release: J4.4, U1.11 (PC3)
/EnvA_Sustain: J4.3, U1.10 (PC2)
/EnvB_Attack: J3.12, U1.12 (PA0)
/EnvB_Decay: J3.11, U1.13 (PA1)
/EnvB_Release: J3.9, U1.24 (PB0)
/EnvB_Sustain: J3.10, U1.17 (PA3)
/Gate1_In: J2.8, R10.1
/Gate1_Inv: Q1.3 (C), R15.1, U1.35 (PB13)
/Gate2_In: J2.9, R11.1
/Gate2_Inv: Q2.3 (C), R16.1, U1.36 (PB14)
/Gate3_In: J2.10, R12.1
/Gate3_Inv: Q3.3 (C), R17.1, U1.37 (PB15)
/Gate4_In: J2.11, R13.1
/Gate4_Inv: Q4.3 (C), R18.2, U1.38 (PC6)
/Gate_In: J1.1, J5.15, J5.16
/LFO_Speed: J2.6, U1.33 (PB11)
/Led1_Out: J3.3, R47.2
/Led2_Out: J3.5, R50.2
/Led3_Out: J3.8, R51.2
/Led4_Out: J3.6, R52.2
/RESET: RESET1.1, U1.7 (NRST)
/SWCLK: J7.4, U1.50 (PA14)
/SWIO: J7.3, U1.49 (PA13)
/UART3_RX: J6.2, U1.53 (PC11)
/UART3_TX: J6.1, U1.62 (PB9)
/USB_DM: J8.2 (D-), U1.45 (PA11)
/USB_DP: J8.3 (D+), U1.46 (PA12)
GND: C1.2, C2.2, C3.2, C4.1, C9.1, C10.1, C11.1, C12.1, C13.1, C14.1, C15.1, C16.2, C17.2, C18.2, C19.2, C20.2, C21.2, C22.1, C23.1, C24.1, C25.1, C26.1, C27.1, C28.1, C29.1, C30.1, J1.6, J1.10, J1.11, J2.1, J3.1, J3.2, J4.5, J5.3, J5.4, J5.5, J5.6, J5.7, J5.8, J7.2, J8.5 (GND), Q1.2 (E), Q2.2 (E), Q3.2 (E), Q4.2 (E), Q5.2 (E), R9.1, R36.2, R38.2, R40.2, R42.2, R53.2, R54.2, R55.2, R56.2, RESET1.2, TP1.1, TP5.1, U1.15 (VSS), U1.27 (VSSA), U1.31 (VSS), U1.47 (VSS), U1.63 (VSS), U2.8 (GND), U3.1 (GND), U4.3 (+), U4.5 (+), U4.10 (+), U4.12 (+), U5.3 (+), U5.5 (+), U5.10 (+), U5.12 (+)
unnamed: C5.2, R1.2, R2.1, U5.1
unnamed: C6.2, R3.2, R4.1, U5.7
unnamed: C7.2, R7.2, R8.1, U5.8
unnamed: C8.2, R5.2, R6.1, U5.14
unnamed: C16.1, R28.1
unnamed: C17.1, R33.1
unnamed: C18.1, R29.1
unnamed: C19.1, R14.1
unnamed: C20.1, R31.1
unnamed: C24.2, U1.5 (PF0), Y1.2
unnamed: C25.2, U1.6 (PF1), Y1.1
unnamed: Q1.1 (B), R10.2
unnamed: Q2.1 (B), R11.2
unnamed: Q3.1 (B), R12.2
unnamed: Q4.1 (B), R13.2
unnamed: Q5.1 (B), R48.2
unnamed: R14.2, R30.1, U2.7 (I_IN2)
unnamed: R19.1, R23.2, U4.2 (-)
unnamed: R20.1, R24.2, U4.6 (-)
unnamed: R21.1, R25.2, U4.9 (-)
unnamed: R22.1, R26.2, U4.13 (-)
unnamed: R27.1, R28.2, U2.10 (I_IN3)
unnamed: R29.2, R34.1, U2.2 (I_IN1)
unnamed: R31.2, U2.1 (MODE)
unnamed: R32.1, R33.2, U2.15 (I_IN4)
unnamed: R36.1, R43.2, U6.2 (-)
unnamed: R38.1, R44.2, U6.6 (-)
unnamed: R40.1, R45.2, U6.9 (-)
unnamed: R42.1, R46.2, U6.13 (-)
unnamed: R43.1, R47.1, R57.1, U6.1
unnamed: R44.1, R50.1, R58.1, U6.7
unnamed: R45.1, R51.1, R59.1, U6.8
unnamed: R46.1, R52.1, R60.1, U6.14
VCC: C2.1, C3.1, C22.2, D1.1 (K), TP3.1, U2.16 (V+), U3.3 (VI), U4.4 (V+), U5.4 (V+), U6.4 (V+)
VEE: C4.2, C21.1, D2.2 (A), TP4.1, U2.9 (V-), U4.11 (V-), U5.11 (V-), U6.11 (V-)

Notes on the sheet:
MCU
Power Supply
Audio Buffers and Envelope Amplifiers
Quad Linear VCA
Connectors
Full Scale: 8V
DAC Envelope scaling for VCA
6k8 and 10k converts 3.3V to 1.96V (max output of VCA) 2.2nF capacitor smooths sampling steps
Could use quad npn transistor pack MMPQ2222A or CD40109B level shifter
Input protection

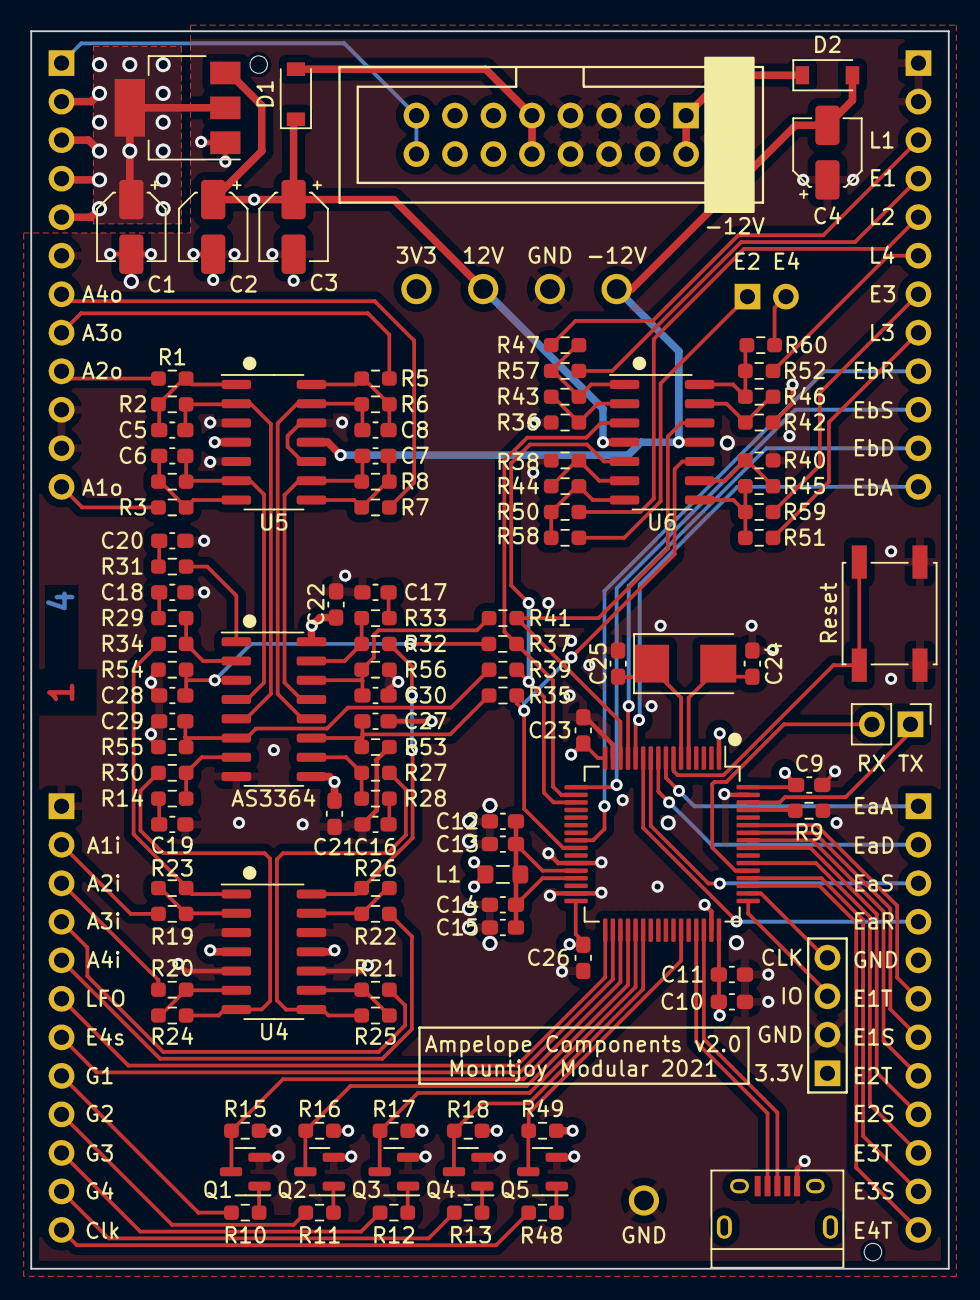
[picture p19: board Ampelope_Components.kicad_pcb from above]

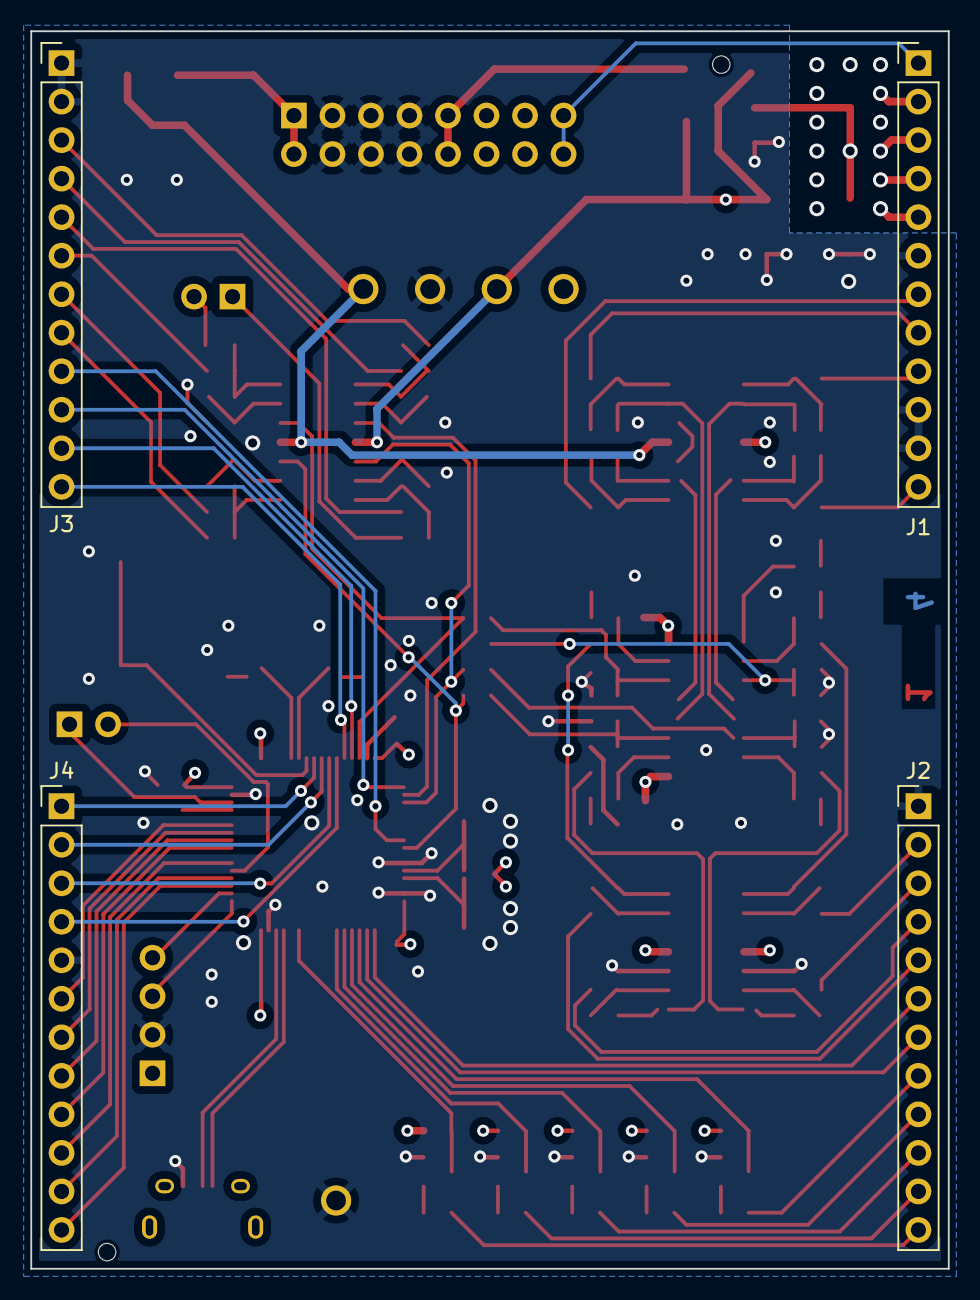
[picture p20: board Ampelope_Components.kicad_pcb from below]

Board: 4 copper layers, 60.5 x 81.6 mm, 123 parts (4 on the bottom side), 108 nets.

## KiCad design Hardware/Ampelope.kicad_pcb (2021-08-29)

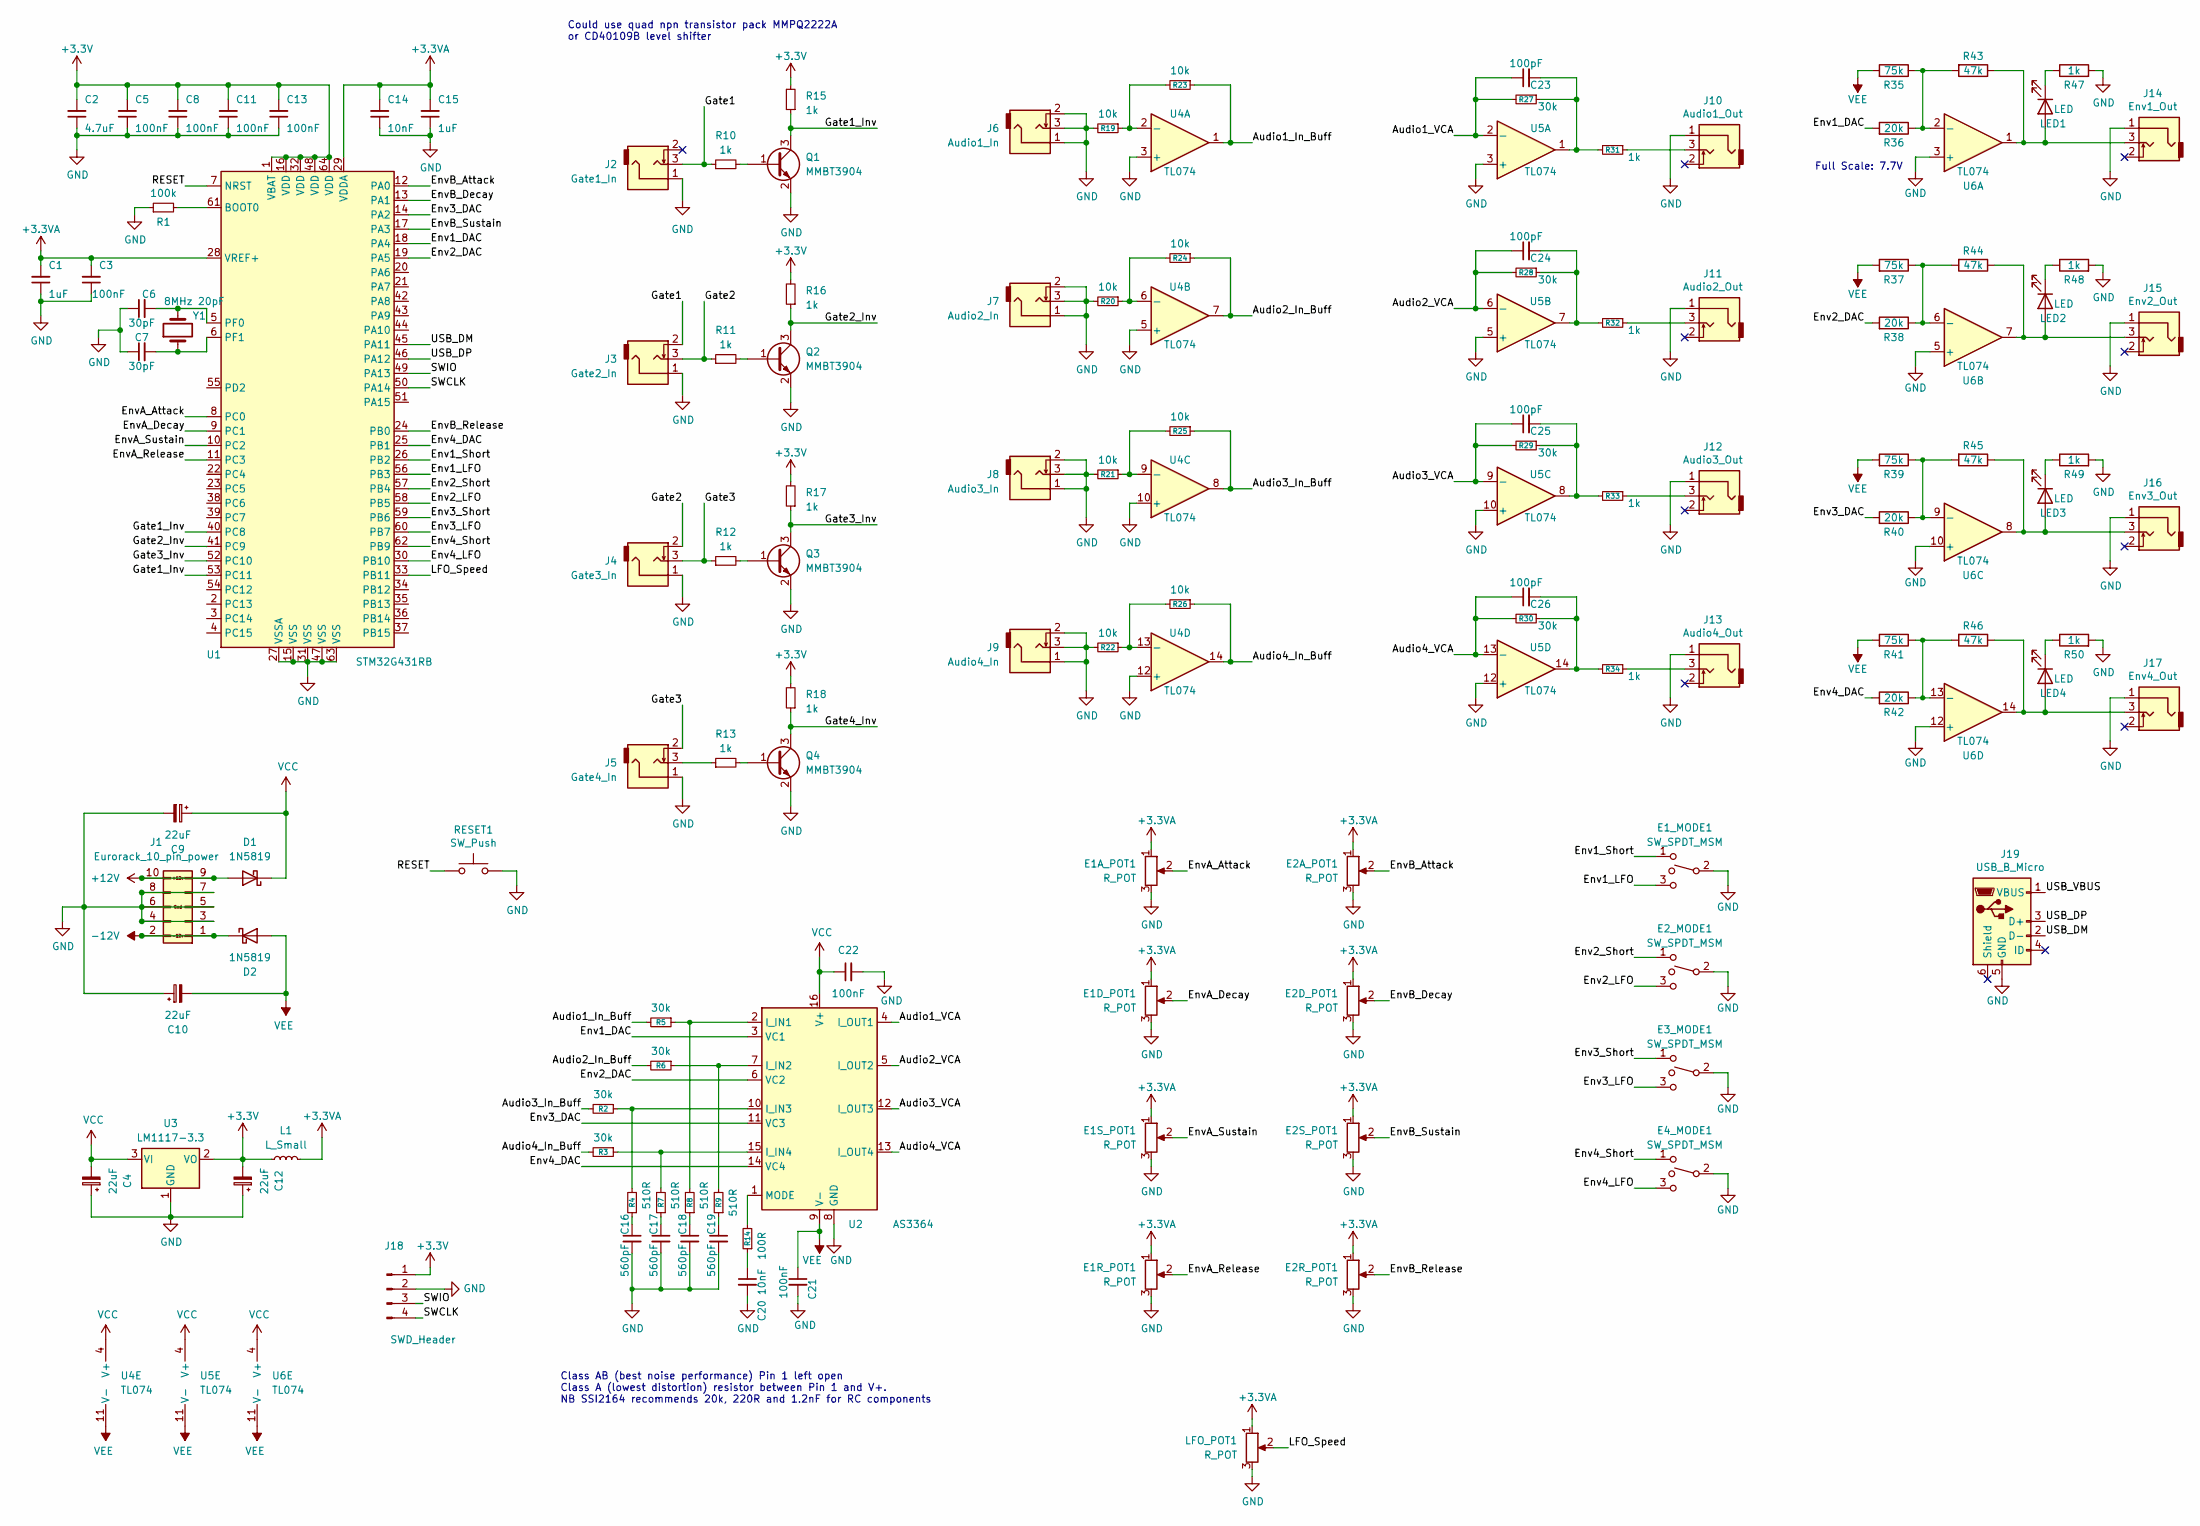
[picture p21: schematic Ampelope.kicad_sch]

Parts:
C1, C15: 1uF; C_0603_1608Metric_Pad1.08x0.95mm_HandSolder
C2: 4.7uF; C_0603_1608Metric_Pad1.08x0.95mm_HandSolder
C3, C5, C8, C11, C13: 100nF; C_0603_1608Metric_Pad1.08x0.95mm_HandSolder
C4, C9, C10, C12: 22uF; CP_Elec_4x5.8
C6, C7: 30pF; C_0603_1608Metric_Pad1.08x0.95mm_HandSolder
C14: 10nF; C_0603_1608Metric_Pad1.08x0.95mm_HandSolder
C16, C17, C18, C19: 560pF; C_0603_1608Metric_Pad1.08x0.95mm_HandSolder; Part_Number C84721
C20: 10nF; C_0603_1608Metric_Pad1.08x0.95mm_HandSolder; Part_Number C57112
C21, C22: 100nF; C_0603_1608Metric_Pad1.08x0.95mm_HandSolder; Part_Number C84721
C23, C24, C25, C26: 100pF; C_0603_1608Metric_Pad1.08x0.95mm_HandSolder
D1, D2: 1N5819; D_SOD-123
E1A_POT1, E1D_POT1, E1R_POT1, E1S_POT1, E2A_POT1, E2D_POT1, E2R_POT1, E2S_POT1: R_POT; Alpha_9mm_Potentiometer_Aligned
E1_MODE1, E2_MODE1, E3_MODE1, E4_MODE1: SW_SPDT_MSM; SPDT_SubMiniature_Aligned
J1: Eurorack_10_pin_power; Eurorack_10_pin_header
J2: Gate1_In; THONKICONN_hole
J3: Gate2_In; THONKICONN_hole
J4: Gate3_In; THONKICONN_hole
J5: Gate4_In; THONKICONN_hole
J6: Audio1_In; THONKICONN_hole
J7: Audio2_In; THONKICONN_hole
J8: Audio3_In; THONKICONN_hole
J9: Audio4_In; THONKICONN_hole
J10: Audio1_Out; THONKICONN_hole
J11: Audio2_Out; THONKICONN_hole
J12: Audio3_Out; THONKICONN_hole
J13: Audio4_Out; THONKICONN_hole
J14: Env1_Out; THONKICONN_hole
J15: Env2_Out; THONKICONN_hole
J16: Env3_Out; THONKICONN_hole
J17: Env4_Out; THONKICONN_hole
J18: SWD_Header; SWD_header
J19: USB_B_Micro; USB_Micro-B_Amphenol
L1: L_Small; L_0805_2012Metric_Pad1.05x1.20mm_HandSolder
LED1, LED2, LED3, LED4: LED; LED_D3.0mm
LFO_POT1: R_POT; Alpha_9mm_Potentiometer_Aligned
Q1, Q2, Q3, Q4: MMBT3904; SOT-23
R1: 100k; R_0603_1608Metric_Pad0.98x0.95mm_HandSolder
R2, R3, R5, R6, R27, R28, R29, R30: 30k; R_0603_1608Metric_Pad0.98x0.95mm_HandSolder; Part_Number C22984
R4, R7, R8, R9: 510R; R_0603_1608Metric_Pad0.98x0.95mm_HandSolder; Part_Number C23193
R10, R11, R12, R13, R15, R16, R17, R18: 1k; R_0603_1608Metric_Pad0.98x0.95mm_HandSolder
R14: 100R; R_0603_1608Metric_Pad0.98x0.95mm_HandSolder; Part_Number C22775
R19, R20, R21, R22, R23, R24, R25, R26: 10k; R_0603_1608Metric_Pad0.98x0.95mm_HandSolder; Part_Number C22984
R31, R32, R33, R34: 1k; R_0603_1608Metric_Pad0.98x0.95mm_HandSolder; Part_Number C22984
R35, R37, R39, R41: 75k; R_0603_1608Metric_Pad0.98x0.95mm_HandSolder; Part_Number C23231
R36, R38, R40, R42: 20k; R_0603_1608Metric_Pad0.98x0.95mm_HandSolder; Part_Number C25803
R43, R44, R45, R46: 47k; R_0603_1608Metric_Pad0.98x0.95mm_HandSolder; Part_Number C25819
R47, R48, R49, R50: 1k; R_0603_1608Metric_Pad0.98x0.95mm_HandSolder; Part_Number C25819
RESET1: SW_Push; SW_PUSH_6mm_aligned
U1: STM32G431RB; LQFP-64_10x10mm_P0.5mm
U2: AS3364; SOIC-16_3.9x9.9mm_P1.27mm
U3: LM1117-3.3; SOT-223-3_TabPin2
U4, U5, U6: TL074; SOIC-14_3.9x8.7mm_P1.27mm
Y1: 8MHz 20pF; Crystal_SMD_5032-2Pin_5.0x3.2mm_HandSoldering; Part_Number C115962

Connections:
+3.3VA: C1.2, C3.2, C14.2, C15.2, E1A_POT1.1, E1D_POT1.1, E1R_POT1.1, E1S_POT1.1, E2A_POT1.1, E2D_POT1.1, E2R_POT1.1, E2S_POT1.1, L1.2, LFO_POT1.1, U1.28 (VREF+), U1.29 (VDDA)
+3V3: C2.2, C5.2, C8.2, C11.2, C12.2, C13.2, J18.1, L1.1, R15.2, R16.2, R17.2, R18.2, U1.1 (VBAT), U1.16 (VDD), U1.32 (VDD), U1.48 (VDD), U1.64 (VDD), U3.2 (VO)
+12V: D1.2 (A), J1.9, J1.10
-12V: D2.1 (K), J1.1, J1.2
/Audio1_In_Buff: R5.2, R23.1, U4.1
/Audio1_VCA: C23.1, R27.2, U2.4 (I_OUT1), U5.2 (-)
/Audio2_In_Buff: R6.2, R24.1, U4.7
/Audio2_VCA: C24.1, R28.2, U2.5 (I_OUT2), U5.6 (-)
/Audio3_In_Buff: R2.2, R25.1, U4.8
/Audio3_VCA: C25.1, R29.2, U2.12 (I_OUT3), U5.9 (-)
/Audio4_In_Buff: R3.2, R26.1, U4.14
/Audio4_VCA: C26.1, R30.2, U2.13 (I_OUT4), U5.13 (-)
/Env1_DAC: R36.2, U1.18 (PA4), U2.3 (VC1)
/Env1_LFO: E1_MODE1.3, U1.56 (PB3)
/Env1_Short: E1_MODE1.1, U1.26 (PB2)
/Env2_DAC: R38.2, U1.19 (PA5), U2.6 (VC2)
/Env2_LFO: E2_MODE1.3, U1.58 (PB5)
/Env2_Short: E2_MODE1.1, U1.57 (PB4)
/Env3_DAC: R40.2, U1.14 (PA2), U2.11 (VC3)
/Env3_LFO: E3_MODE1.3, U1.60 (PB7)
/Env3_Short: E3_MODE1.1, U1.59 (PB6)
/Env4_DAC: R42.2, U1.25 (PB1), U2.14 (VC4)
/Env4_LFO: E4_MODE1.3, U1.30 (PB10)
/Env4_Short: E4_MODE1.1, U1.62 (PB9)
/EnvA_Attack: E1A_POT1.2, U1.8 (PC0)
/EnvA_Decay: E1D_POT1.2, U1.9 (PC1)
/EnvA_Release: E1R_POT1.2, U1.11 (PC3)
/EnvA_Sustain: E1S_POT1.2, U1.10 (PC2)
/EnvB_Attack: E2A_POT1.2, U1.12 (PA0)
/EnvB_Decay: E2D_POT1.2, U1.13 (PA1)
/EnvB_Release: E2R_POT1.2, U1.24 (PB0)
/EnvB_Sustain: E2S_POT1.2, U1.17 (PA3)
/Gate1: J2.3, J3.2, R10.1
/Gate1_Inv: Q1.3 (C), R15.1, U1.40 (PC8), U1.53 (PC11)
/Gate2: J3.3, J4.2, R11.1
/Gate2_Inv: Q2.3 (C), R16.1, U1.41 (PC9)
/Gate3: J4.3, J5.2, R12.1
/Gate3_Inv: Q3.3 (C), R17.1, U1.52 (PC10)
/Gate4_Inv: Q4.3 (C), R18.1
/LFO_Speed: LFO_POT1.2, U1.33 (PB11)
/RESET: RESET1.1, U1.7 (NRST)
/SWCLK: J18.4, U1.50 (PA14)
/SWIO: J18.3, U1.49 (PA13)
/USB_DM: J19.2 (D-), U1.45 (PA11)
/USB_DP: J19.3 (D+), U1.46 (PA12)
/USB_VBUS: J19.1 (VBUS)
GND: C1.1, C2.1, C3.1, C4.1, C5.1, C6.1, C7.1, C8.1, C9.2, C10.1, C11.1, C12.1, C13.1, C14.1, C15.1, C16.2, C17.2, C18.2, C19.2, C20.2, C21.2, C22.2, E1A_POT1.3, E1D_POT1.3, E1R_POT1.3, E1S_POT1.3, E1_MODE1.2, E2A_POT1.3, E2D_POT1.3, E2R_POT1.3, E2S_POT1.3, E2_MODE1.2, E3_MODE1.2, E4_MODE1.2, J1.3, J1.4, J1.5, J1.6, J1.7, J1.8, J2.1, J3.1, J4.1, J5.1, J6.1, J6.2, J6.3, J7.1, J7.2, J7.3, J8.1, J8.2, J8.3, J9.1, J9.2, J9.3, J10.1, J11.1, J12.1, J13.1, J14.1, J15.1, J16.1, J17.1, J18.2, J19.5 (GND), LFO_POT1.3, Q1.2 (E), Q2.2 (E), Q3.2 (E), Q4.2 (E), R1.1, R19.2, R20.2, R21.2, R22.2, R47.2, R48.2, R49.2, R50.2, RESET1.2, U1.15 (VSS), U1.27 (VSSA), U1.31 (VSS), U1.47 (VSS), U1.63 (VSS), U2.8 (GND), U3.1 (GND), U4.3 (+), U4.5 (+), U4.10 (+), U4.12 (+), U5.3 (+), U5.5 (+), U5.10 (+), U5.12 (+), U6.3 (+), U6.5 (+), U6.10 (+), U6.12 (+)
unnamed: C6.2, U1.5 (PF0), Y1.2
unnamed: C7.2, U1.6 (PF1), Y1.1
unnamed: C16.1, R4.1
unnamed: C17.1, R7.1
unnamed: C18.1, R8.1
unnamed: C19.1, R9.1
unnamed: C20.1, R14.1
unnamed: C23.2, R27.1, R31.2, U5.1
unnamed: C24.2, R28.1, R32.2, U5.7
unnamed: C25.2, R29.1, R33.2, U5.8
unnamed: C26.2, R30.1, R34.2, U5.14
unnamed: J5.3, R13.1
unnamed: J10.3, R31.1
unnamed: J11.3, R32.1
unnamed: J12.3, R33.1
unnamed: J13.3, R34.1
unnamed: LED1.1 (K), R47.1
unnamed: J14.3, LED1.2 (A), R43.1, U6.1
unnamed: LED2.1 (K), R48.1
unnamed: J15.3, LED2.2 (A), R44.1, U6.7
unnamed: LED3.1 (K), R49.1
unnamed: J16.3, LED3.2 (A), R45.1, U6.8
unnamed: LED4.1 (K), R50.1
unnamed: J17.3, LED4.2 (A), R46.1, U6.14
unnamed: Q1.1 (B), R10.2
unnamed: Q2.1 (B), R11.2
unnamed: Q3.1 (B), R12.2
unnamed: Q4.1 (B), R13.2
unnamed: R1.2, U1.61 (BOOT0)
unnamed: R2.1, R4.2, U2.10 (I_IN3)
unnamed: R3.1, R7.2, U2.15 (I_IN4)
unnamed: R5.1, R8.2, U2.2 (I_IN1)
unnamed: R6.1, R9.2, U2.7 (I_IN2)
unnamed: R14.2, U2.1 (MODE)
unnamed: R19.1, R23.2, U4.2 (-)
unnamed: R20.1, R24.2, U4.6 (-)
unnamed: R21.1, R25.2, U4.9 (-)
unnamed: R22.1, R26.2, U4.13 (-)
unnamed: R35.1, R36.1, R43.2, U6.2 (-)
unnamed: R37.1, R38.1, R44.2, U6.6 (-)
unnamed: R39.1, R40.1, R45.2, U6.9 (-)
unnamed: R41.1, R42.1, R46.2, U6.13 (-)
VCC: C4.2, C9.1, C22.1, D1.1 (K), U2.16 (V+), U3.3 (VI), U4.4 (V+), U5.4 (V+), U6.4 (V+)
VEE: C10.2, C21.1, D2.2 (A), R35.2, R37.2, R39.2, R41.2, U2.9 (V-), U4.11 (V-), U5.11 (V-), U6.11 (V-)

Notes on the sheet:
Class AB (best noise performance) Pin 1 left open Class A (lowest distortion) resistor between Pin 1 and V+. NB SSI2164 recommends 20k, 220R and 1.2nF for RC components
Could use quad npn transistor pack MMPQ2222A or CD40109B level shifter
Full Scale: 7.7V

Board: 2 copper layers, 127 parts (0 on the bottom side), 90 nets, no tracks yet.

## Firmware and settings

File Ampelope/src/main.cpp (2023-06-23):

#include "initialisation.h"
#include "envelope.h"
#include "usb.h"
#include "uartHandler.h"
#include "SerialHandler.h"
#include <cmath>
// FIXME - add transistor to start VCA in off position

volatile uint32_t SysTickVal;
volatile ADCValues adc;

uint32_t buttonDebounce;
Envelopes envelopes;
USBHandler usb;
SerialHandler serial(usb);

extern "C" {
#include "interrupts.h"
}


extern uint32_t SystemCoreClock;
int main(void)
{
	SystemInit();							// Activates floating point coprocessor and resets clock
	SystemClock_Config();					// Configure the clock and PLL
	SystemCoreClockUpdate();				// Update SystemCoreClock (system clock frequency) derived from settings of oscillators, prescalers and PLL
	InitSysTick();
	InitDAC();
	InitIO();
	InitEnvTimer();
	InitADC(reinterpret_cast<volatile uint16_t*>(&adc));
	InitUart();
	InitCordic();

	usb.InitUSB();

	while (1) {
		if ((GPIOC->IDR & GPIO_IDR_ID13) != 0 && SysTickVal > buttonDebounce + 1000) {
			buttonDebounce = SysTickVal;
#if (USB_DEBUG)
			usb.OutputDebug();
#endif
		}
		serial.Command();			// Check for incoming CDC commands
	}
}

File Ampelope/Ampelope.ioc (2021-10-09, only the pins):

Mcu.UserName=STM32G431RBTx
PA1.Signal=OPAMP3_VINP
PA13.GPIO_Label=T_SWDIO
PA13.Signal=SYS_JTMS-SWDIO
PA14.GPIO_Label=T_SWCLK
PA14.Signal=SYS_JTCK-SWCLK
PA2.GPIO_Label=LPUART1_TX [STLINKV3E_VCP_RX]
PA2.Signal=LPUART1_TX
PA3.GPIO_Label=LPUART1_RX [STLINKV3E_VCP_TX]
PA3.Signal=LPUART1_RX
PA4.Signal=COMP_DAC11_group
PA5.GPIO_Label=LD2 [green]
PA5.Signal=GPIO_Output
PB1.Signal=OPAMP3_VOUT
PB3.GPIO_Label=T_SWO
PB3.Signal=SYS_JTDO-SWO
PC13.GPIO_Label=B1 [blue push button]
PC13.Signal=GPXTI13
PC14-OSC32_IN.Signal=RCC_OSC32_IN
PC15-OSC32_OUT.Signal=RCC_OSC32_OUT
PC4.Signal=USART1_TX
PF0-OSC_IN.Signal=RCC_OSC_IN
PF1-OSC_OUT.Signal=RCC_OSC_OUT

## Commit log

2021-06-23 Added STM32G431 project; clock configuration complete
    [Ampelope-B_Cu.gbr, Ampelope-B_Mask.gbr, Ampelope-B_Silkscreen.gbr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]
2021-07-03 Started implementing ADSR Code
    [Ampelope.kicad_sch]
2021-07-05 Started schematic; basic envelope working on timer
    [Ampelope.kicad_pcb, Ampelope.kicad_sch, Ampelope.sch]
2021-07-08 ADC and DMA configured and working
2021-07-09 Added additional DAC/Opamp channel
    [Ampelope.kicad_sch]
2021-07-15 Started implementing USB RX interrupt
2021-07-16 Working up to set address (though issues with DATA0/1 toggling)
    [USB.cpp]
2021-07-17 More work on USB - trying to fix issues with EP0R values
    [USB.cpp, USB.h]
2021-07-19 Added UART Handler for debugging
2021-07-19 Starting setting up USB debug output via Nucleo UART/user button
2021-07-22 Fixed bug: working up to stage of split transfer
    [USB.cpp]
2021-07-29 USB Serial receive working (not fully tested)
    [amp_usb.csv, hal_usb.csv, merged.xlsx]
2021-07-30 Improvements to CDC line coding routine
    [amp_usb.csv]
2021-07-31 Fixed sending and receiving long strings
    [USB.cpp]
2021-08-01 More code clean up; fixed issue disconnecting and reconnecting USB
    [USB.cpp]
2021-08-01 Macro clean up; fixed issue receiving large packets
    [USB.cpp, USB.h]
2021-08-06 Fixed bug transmitting USB buffer whose size is a multiple of 64
    [USB.cpp, USB.h]
2021-08-09 Starting modelling attack curves from Roland clone ADSR
    [Ampelope.kicad_sch]
2021-08-10 Fixed very slow performance and updated attack magic numbers to compensate
    [envelope.cpp]
2021-08-13 Updated envelope model for full ADSR, long and short times
    [envelope.cpp, uartHandler.cpp]
2021-08-16 Added additional ADC channels for Envelope 1 ADSR controls
    [Ampelope.kicad_sch]
2021-08-16 Envelope 1 with VCA working; schematic updated
    [Ampelope.kicad_sch]
2021-08-19 More CORDIC tests; schematic updates
    [Ampelope.kicad_sch]
2021-08-27 Added power supply components to schematic
    [Ampelope.kicad_sch]
2021-08-27 Duplicated IO for all four envelopes/VCAs
    [Ampelope.kicad_sch]
2021-08-28 Added switches and poteniometers to schematic
    [Ampelope.kicad_sch]
2021-08-28 More work on schematic
    [Ampelope.kicad_sch]
2021-08-29 Preliminary pcb layout preparation
    [Ampelope-B_Cu.gbr, Ampelope-B_Mask.gbr, Ampelope-B_Silkscreen.gbr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]
2021-08-30 Split PCBs into separate control and component boards
    [Ampelope.kicad_sch, Ampelope_Controls.kicad_pcb, Ampelope_Controls.kicad_sch]
2021-08-31 First Draft Layout of controls PCB
    [Ampelope.kicad_sch, Ampelope_Controls.kicad_pcb, Ampelope_Controls.kicad_sch]
2021-09-01 Started rough placement of component board
    [Ampelope_Components.kicad_pcb, Ampelope_Components.kicad_sch, Ampelope_Controls.kicad_pcb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]
2021-09-01 More layout of component board
    [Ampelope_Components.kicad_pcb, Ampelope_Components.kicad_sch]
2021-09-01 More layout on component board
    [Ampelope_Components.kicad_pcb, Ampelope_Components.kicad_sch]
2021-09-02 More component layout
    [Ampelope_Components.kicad_pcb, Ampelope_Components.kicad_sch]
2021-09-04 Draft of panel layout
    [Ampelope_Components.kicad_pcb, Ampelope_Components.kicad_sch, Ampelope_Panel.kicad_pcb]
2021-09-05 Work on panel and control layout
    [Ampelope_Controls.kicad_pcb, Ampelope_Panel.kicad_pcb]
2021-09-06 First draft of panel and control boards complete
    [Ampelope_Controls.kicad_pcb, Ampelope_Panel.kicad_pcb]
2021-09-07 Layout on component board
    [Ampelope_Components.kicad_pcb, Ampelope_Components.kicad_sch, Ampelope_Controls.kicad_pcb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]
2021-09-08 Component layout refinement; pre change of input protection transistors to PNPs
    [Ampelope_Components.kicad_pcb, Ampelope_Components.kicad_sch]
2021-09-09 Updated to work correctly with AS3364 (gain levels, non inverting etc)
    [Ampelope_Components.kicad_pcb, Ampelope_Components.kicad_sch, Measured response of AS3364 VCA control curve.xlsx]
2021-09-09 Updates to component PCB to reflect VCA schematic changes
    [Ampelope_Components.kicad_pcb, Ampelope_Components.kicad_sch]
2021-09-11 Added test points to component PCB; Added 3D mockups
    [Ampelope_Components.kicad_pcb, Ampelope_Components.kicad_sch, Ampelope_Controls.kicad_pcb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]
2021-09-11 Wired up control board
    [Ampelope_Controls.kicad_pcb]
2021-09-11 Fixed DRC errors on control and component boards
    [Ampelope_Components.kicad_pcb, Ampelope_Components.kicad_sch, Ampelope_Controls.kicad_pcb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]
2021-09-13 Code to start testing tremolo clock circuit
    [Ampelope_Components.kicad_pcb]
2021-09-14 Tremolo can be clock synched; increased accuracy of CORDIC exp calculation to fix bug w long releases
    [envelope.cpp]
2021-09-15 Various schematic and PCB tidying
    [Ampelope_Components.kicad_pcb, Ampelope_Components.kicad_sch, Ampelope_Controls.kicad_pcb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]
2021-09-16 Minor PCB cleanup
    [Ampelope_Components.kicad_pcb]
2021-09-18 Further PCB tidy up and DAC testing
    [Ampelope_Components.kicad_pcb, Ampelope_Components.kicad_sch, Ampelope_Controls.kicad_pcb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]
2021-09-23 Changed input protection diodes back to 3904s; prepared gerbers
    [Ampelope_Components-B_Cu.gbr, Ampelope_Components-B_Mask.gbr, Ampelope_Components-B_Paste.gbr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]
2021-09-23 Prepared gerbers for pcb manufacture
    [Ampelope_Components-B_Cu.gbr, Ampelope_Components-B_Mask.gbr, Ampelope_Components-B_Paste.gbr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]
2021-10-09 Fixes to component schematic and pcb (power supply and silkscreen); Firmware updated to use correct pin assignments
    [Ampelope_Components.kicad_pcb, Ampelope_Components.kicad_sch]
2021-10-12 Various bug fixes and code tidying
    [Ampelope_Components.kicad_sch]
2021-10-12 Tremolo clocking working correctly with multipliers
    [envelope.cpp]
2022-03-14 Updated to Kicad v6
    [Ampelope_Components.kicad_pcb, Ampelope_Controls.kicad_pcb, Ampelope_Panel.kicad_pcb]
2023-03-01 Created Adapter Board to break out Quad signals
    [Ampelope_Adapter.kicad_pcb, Ampelope_Adapter.kicad_sch]
2023-03-02 Fixes to Adapter Board
    [Ampelope_Adapter-B_Cu.gbr, Ampelope_Adapter-B_Mask.gbr, Ampelope_Adapter-B_Silkscreen.gbr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]
2023-03-03 Added dummy connector
    [Ampelope_Adapter-B_Cu.gbr, Ampelope_Adapter-B_Mask.gbr, Ampelope_Adapter-B_Silkscreen.gbr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]
2023-06-23 Update adc naming conventions
